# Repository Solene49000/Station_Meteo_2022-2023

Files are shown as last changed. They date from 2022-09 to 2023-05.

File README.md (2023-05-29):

INTRODUCTION
-
Dans le cadre du projet de la ruche connectée, nous continuons le développement de la station météo.
Celle ci permet  la mesure de données météorologiques telles que :
- La quantité de pluie tombée (1 front montant par basculement du pluviomètre)
- La vitesse du vent (1 front montant par tour d'anémomètre)
- La direction du vent (Tension différente par direction)
- La luminosité (I2C)
- La température (I2C)
- L'humidité (I2C)

Le code final nommé **test_sleep** est situé dans le repertoire : *Codes/Dernière version* : [https://github.com/Solene49000/Station_Meteo_2022-2023/tree/main/Codes/Derni%C3%A8re_version/test_sleep]

1 - LES PORTS
-

- Les ports LoRa
  - SCK : 18 -- Horloge SPI
  - MISO : 19 -- Master In Slave Out SPI
  - MOSI : 23 -- Master Out Slave In SPI
  - SS : 5 -- Select Slave = NSS SPI
  - RST : 14 -- Reset
  - DI0 : 26 -- Données
  
- Les ports de modules
  - ANEMOMETRE : 27 -- Récupère données anémomètre
  - PLUVIOMETRE : 32 -- Récupère données pluviomètre
  - GIROUETTE : 36 -- Récupère données girouette

- Autres ports
  - MEASURE : 13 -- Mettre à high pour fournir une tension aux modules
  - LED_R : 33 -- Led rouge de test du bon fonctionnement
  - LED_G : 25 -- Led verte de test du bon fonctionnement

2- LES FICHIERS
-
- test_sleep.ino : Demande à des fréquences régulières la restitution des données des modules et envoie la trame LoRa
- Girouette.ino : Renvoie la direction du vent entre 0 et 15 ( 0 = Nord, 1 = Nord Nord Ouest, ...)
- Anemometre.ino : Renvoie la vitesse du vent jusquà 250 km/h (float)
- Pluviometre.ino : Renvoie la quantité d'eau tombée en 10s
- LuxHumTemp.ino : 
  - Renvoie la luminosité en lux
  - Renvoie l'humidité en pourcentage
  - Renvoie la température en degrés
- ESP_LoRa_internal.ino : 
  - Appelle 3 fonctions
    - build_trame : écrit une trame avec les données brutes de nos mesures
    - debug_trame : reformate la trame en binaire
    - lora_send_trame : envoie la trame vers l'antenne
- Batterie.ino : Renvoie la tension de la batterie
 
3 - LES DETAILS
-
- Une trame LoRa est envoyée toutes les 15 minutes
- Structure trame :   I|macAdresse|pluviomètre|anémomètre|girouette|partie_1_pression|partie_2_pression|humidité|luminosité|température|batterie|checkbytes

4 - LE SET UP
-
- Télécharger Arduino IDE
- Télécharger toutes les librairies affichées dans le fichier concerné
- Paramétrer Arduino IDE pour accepter la carte ESP32 Dev Module
- Copier le code issu de github : ouvrir le terminal de commande, allez dans votre répertoire du projet et entrez la fonction suivante "git copy https://github.com/Solene49000/Station_Meteo_2022-2023/tree/main/Codes"
- Dans documents, ouvrir le fichier "Station_meteo.ino". Tous les fichiers du dossier s'ouvrent dans Arduino
- Préparer le set up :
  - Brancher le pluviomètre au connecteur P
  - Brancher l'anémomètre et la girouette au connecteur G
  - Brancher le câble USB à la carte Arduino et à votre PC
- Compiler puis téléverser le code ( La compilation peut s'avérer très longue car Arduino n'est pas vraiment adapté à Windows et nous avons un certain nombre de fichiers)

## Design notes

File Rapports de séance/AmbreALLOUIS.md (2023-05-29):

Rapport de séance
==

Présentation du projet
-

Séance du 01/09/2022
-

- Mise en place du projet Station Météo 2022-2023 :
  - Création du projet sur github
  - Ajout de dossiers : Rapports de séance et Docs
  - Ajout dans le dossier Docs de la documantation sur notre projet
  - Ajout des rapports de Solène Guillaume et Ambre Allouis dans Rapports de séance
  - Prise en main du langage Markdown
- Matériel à disposition :
  - Anémomètre : Vitesse du vent
  - Capteur de direction du vent
  - Pluviomètre : Compte le nombre de bascule
  - Capteur de lumière
  - Capteur de température, d'hydrométrie, de pression atmosphérique
  - Abris météo

Séance du 02/09/2022
-

- Récupération du schéma de la carte et du tableau.
- Lecture des rapports de l'année précédente
- Lecture des codes récupérés de l'année précédente : Les codes fournis ne sont pas bons, il manque la version finale.
- Installation et configuration d'Arduino :
  - Installation des librairies ESP32 et LoRa.
  - Analyse et compilation du code fourni
  - Choix du Port COM3
  - Outils : Carte ESP32 Dev
  - Création d'un code permettant de faire clignoter les deux led (LED_R et LED_G) pour vérifier l'accès à la carte.  

Séance du 09/09/2022
-

- On a recompilé le code permettant de faire alterner la led verte et la led rouge
- Pluie : détection par 1 front montant par routine + détection dès que la pluie tombe
- Vent changement : plusieurs fronts montant et descendants créés donc soit création d’un filtre et ou détection par rebond
- Pour la girouette : retourne 16 valeurs en fonction de la direction du vent. Les élèves précédents ont utilisé un générateur de tension. Chaque sortie est associée à une tension particulière. Le problème de ce fonctionnement est lié à la tension fournit par la batterie qui oscille entre 3,1 et 3,6 V. cet intervalle cause la proximité des tensions entre chaque sortie et fausse les résultats.
- M Peter nous a donc conseillé d’utiliser un générateur de courant car celui-ci n’est pas influencé par la différence de tension.

Séance du 15/09/2022
-

- Pluviometre, utilisation de la commande attachInterrupt() utilisation de la fonctionnalité FALLING permettant la dettection des fronts descendants
- cette fonction permet d'incrémenter une variable et de retourner chaque changement d'état
- le pluviometre est relie au port GIO 32, pour le fonctionnement initiale du pluviomêtre il reçoit V+. Pour notre cas, il est allimenté par VCC, donc pour obtenir la tension initiale, on pinMODE MEASURE à l'état 1 cette variable nous permet d'imposer le passage au niveau des transistor et ainsi de distribuer la bonne tension. Le transistor étant passant, le condo permet d'éviter l'é=effet de rebond. De plus lorsque la carte est débranchée puis rebranchée, le compteur  est incrémenté de 2.

anemo : installation de la librairie esp32 timerInterrupt

Séance du 03/10/2022
-

Codage de la partie Anémomètre :
- Recherche de bibliothèques timer associées à l'ESP32, nous ajoutons donc la bibliothèque ESP32TimerInterrupt
- Sans l'utilisation de cette bibliothèque, nous arrivons à afficher le nombre de tours de l'anémomètre et la vitesse du vent. en fin de séance nous nous sommes rendu compte que le calcul n'est pas correcte.
- Pour la réalisation de ce programme nous utilisaons la fonction delay. Le problème de cette fonction est que le programme est bloqué lors de sont activation. Donc cette fonction n'est pas compatible avec les autres codes.
- Le codage de l'anemomètre est en cours avec l'utilisation de la nouvelle librairie

Séance du 13/10/2022
-

- Utilisation de la bibliothèque ESP32TimerInterrupt :
  Cette bibliothèque nous permet de creer une fonction permettant l'interruption d'un programme à un moment donné dans une ISR. Pour notre cas, celle ci nous permet de relever la vitesse du vent. Pour notre cas d'essai, nous avons decidé de récupérer la vitesse toutes les 30 secondes.
  Pour la réalisation de cette fonction, nous avons utilisé les commandes suivantes :
    - My_timer = timerBegin(0, 80, true); --> Cette commande initialise la variable My_timer avec un numéro de timer, une valeur de prescaler et le mode compteur (true) 
    - timerAttachInterrupt(My_timer, &onTimer, true); --> Ici on fait appel à la fonction onTimer avec les paramètres de la variable My_timer
    - timerAlarmWrite(My_timer, tempsTimer*1000000, true); --> Maintenant, nous deffinissons le temps entre chaque interuption. Cette valeur est en microsecondes. Pour faciliter les calculs qui suivent, nous avons décidé de créer une variable comprenant le temps d'attente en secondes. Pour avoir le temps en microsecondes, nous multiplions cette variable avec la puissance associée (10^6).
    - timerAlarmEnable(My_timer); --> Activation de l'interruption
--> Nous avons fait le choix d'utiliser une librairie afin de clarifier et simplifier notre code lorsque toutes les parties seront réunies.
- Pour calculer la vitesse du vent, nous avons utilise=é le calcul suivant : vitesseVent = (PI * RAYON * 2 * tourAnemo)/tempsTimer*3.6 ;
  Nous multiplions la circonférence de l'anemomètre par le nombre de tours et le divisons par le temps en secondes. Le résultat obtenu est en m/s, nos le multiplions donc par 3.6 pour avoir ce résultat en km/h. 
- Le code de l'anémomètre est maintenant opérationnel et complet.

Séance du 28/10/2022
-

- installation de la librairie TSL2591 library
- installation de la librairie bluedot BME280 TSL2591
- Librairies BME hors de Arduino, recherche et téléchargement des dossiers nécéssaires

Séance du 18/11/2022
-

- Réalisation du code capteur de lumière

Séance du 25/11/2022
-

- Récupération du code de l'équipe de l'année dernière
- Installation de la librairie Adafruit
- Le code de l'année passé ne fonctionne pas, les valeurs globales : temperature, pression et humidite restent à 0. 

Séance du 01/12/2022
-

- Réalisation du code capteur de lumière et capteur de pression, humidité et température
- Installation des librairies :
  - Adafruit
  - ESP32 Time Interrupt
- Création du répertoire bibliothèques. Ce repertoire contient, un fichier texte avec la liste de toutes les bibliothèques installées et les fonctions qui les utilisent et les répertoires ".zip" à inclurent dans arduino.

Séance du 09/12/2022
-

- Finalisation du code capteur de lumière et capteur de pression, humidité et température
- La fonction interrupt / timer de l'ESP32, retourne des erreurs et empêche la bonne lecture des résultats.
  Le problème provient de la tension renvoyée par le système, elle est trop élevée.
  Au final, on a choisi de ne pas faire appel à cette fonction parce que pour le code final, on va récupérer toutes les données en mêmes temps. Pour cela, cette fonction ne nous sera pas utile.
- Mise en commun des codes et réalisation d'un main récupérant toutes les données à un interval de temps donné.

Séance du 20/12/2022
-

- Travail sur le système de récupération des données avec une trame LoRa
- LoRa : est un protocol réseau. Elle permet la modulation d'ondes radio et une transmission radio longue portée à bas débit. Cette technologie est la plus adaptée à notre système parce qu'on doit communiquer peu d'informations et peu souvent. Notre système est positionner à l'extérieur et doit communiquer avec une application située plus loin.
- Lors de cette séance, j'ai mal compris une de nos discussion. J'ai travaillé sur une interface web qui receptionne la trame LoRa. Cependant, l'application que nous devons rejoindre est déjà existante. Au final, j'ai perdu le temps d'une séance pour le projet.  

Séance du 06/01/2023
-

- Travail en binome sur la trame LoRa.
- Le code fourni n'est pas compilable, séance de débuggage.
- On relève un problème de fréquence pour la transmission.
- L'initialisation de la fréquance n'est pas fonctionnelle.
- La définition de type pour certaines fonctions était mal effectuée et provoquait des erreur : changement du type build en void.

Séance du 19/01/2023
-

- Présentation de notre avancée sur le projet
- Nous devons inclure dans notre code :
  - Lecture de la tension de le batterie et l'ajouter dans la trame LoRa
  - Ajouter un système de réveil. Celui-ci enverrai une fois réveillé toutes les données avec la trame LoRa et endormi compte le nombre de bascules du pluviomètre. 

Séance du 10/02/2023
-

- Choix du mode deep sleep car il consomme peu et il peut enregistrer des données même pendant sa phase endormie. 
- Le système est réveillé par toutes les interruptions.

Séance du 17/02/2023
-

Séance du 16/03/2023
-

Séance du 23/03/2023
-

- Ajout dans le code du sleep mode.
- Objectif : ne pas reveiller le systeme avec les bascules du pluviomètre.

Séance du 28/03/2023
-

- Utilisation du deep sleep, le microcontroleur, ne détecte pas les bascules.
- Test du slight sleep, fonctionne très bien, on arrive à récuperer le nombre de bascules. Mais le problème est que ce système consomme beaucoup trop.
- On bascule donc sur le deep sleep, le problème viendrait du code, il serait appelé au mauvais endroit.

Séance du 06/04/2023
-

- Comparaison entre l'heure du actuelle et l'heure de l'interruption pour compter les bascules.
- Fonctionnement du timer.

Séance du 20/04/2023
-

- Préparation du support de présentation
- On relève un problème lors du réveil du pluviomètre. Le deep sleep aurait un problème d'initialisation. Lors de la première mise en veille avant la première phase de réveil du système. Le deep sleep remonte bien le nombre de bascules du pluviomètre. Lors du premier réveil, la trame LoRa est bien transmise. Après commence la deuxième phase de mise en veille et là nous rencontrons un problème avec le temps de réveil. Ce problème provoque des bascules systématiques du pluviomètre.
- Nous avons remarqué que le temps d'interruption correspond toujours à celui de la première phase.

Séance du 27/04/2023
-

Présentation du projet

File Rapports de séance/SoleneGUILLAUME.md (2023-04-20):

CAHIER DE SUIVI - SOLENE GUILLAUME
==
SEANCE I - 01 Sept : Présentation du projet
-
Lots de cette séance, nous avons recu des explications sur le projet Ruche connectée. <br/> 

### Ruche connectée #

La ruche connectée est divisé en plusieurs projets différents. <br/>Notre promo prend la suite de ce qui est existant.
<br/> Trois grosses parties sont à créer ou bien à continuer.
- La station météo (à continuer)
- Lutte contre les parasites
- Communication GSM et WiFi

Nous nous occuperons de la partie station météo. <br/> 
Il nous faudra pour ceci créer une interface utilisateur affichant les données météorologiques captées. <br/>

### Matériel à disposition #
- Pluviomètre
- Anémomètre
- Girouette
- Capteur de luminosité (TSL2591)
- Capteur de température, d'hydrométrie et de pression atmosphérique (BME/BMP280)
- Microcontroleur ESP32 

### Avancées #

- Présentation du projet
- Choix du sujet
- Prise en main de Github
- Création du Repository sur Github
- Organisation du Repository
- Ajout des documents et liens utiles dans le repository
- Creation du fichier de cahier de suivi
- Prise en main du langage markdown 

SEANCE II - 02 Sept : Recupération des fichiers
-

- Recupération du schéma et du PCB 
  - Pluviomètre = connecteur gauche et girouette = connecteur droit
- Recupération du GitHub de l'année dernière
  - Lecture des documents 
- Sur Arduino : installation des libraires ESP32 et LoRa
- Outils : Carte ESP32 Dev et Port COM3
- Test des codes donnés l'année dernière : ne fonctionnent pas
- Creation d'un code pour tester compilation et bon fonctionnement de la carte : les leds s'allument

SEANCE III - 09 Sept : Commencement du code du pluviomètre
-
- Recompilation du code des Leds sur Arduino
- Separation des taches
  - Ambre : Pluviomètre et Anémomètre
  - Solène : Girouette  
- Lien pour infos du materiel https://www.lextronic.fr/anemometre-pluviometre-girouette-compatible-arduino-microbit-grove-63661.html
- Lien pour code Arduino sur le matériel : http://atelier-meteo-arduino-lycee-vincendo.blogspot.com/p/le-pluviometre.html
- La Girouette donne 16 valeurs selon la direction d'où vient le vent
  - Impossible de téléverser le code
  - L'année dernière, les eleves ont fait un pont diviseur de tension. En le testant, il est apparu que les mesures de tension prises n'ont pas satisfait car trop proches. 
  - A la place, Monsieur Peter nous a conseillé de renmplacer la résistance principale par un générateur de courant.
  - Les prochaines séances, nous allons nous concentrer sur les autres appareils.
 - Concernant le pluviomètre et l'anémomètre :
  -   l'interrupeur fait des rebonds. Il faut pour ceci faire en sorte dans notre code de ne pas prendre en compte ces faux rebonds pour ne pas fausser la mesure.

SEANCE IV - 15 Sept : Pluviomètre
-
- Probleme sur pluviomètre : Ne detectait pas les fronts montants
  - Avec l'aide de M. Peter, de l'oscilloscope et du schéma, nous avons compris que V+ n'etait pas assez alimenté
  - Ceci car des transistors étaient bloqués. Il faut les rendre passants. Sur arduino : mettre la pin MEASURE à HIGH
  - Maintenant V+ est alimenté et les transitions 0 --> 1 franches. Le code marche et nous arrivons à avoir un compte des clics.
- Grace à l'ajout l'année dernière d'un condensateur, nous n'avons plus de rebonds entre chaque incrémentation. Le compte est propre.
- Pour l'anemometre : nous arrivons compter les switchs. Il faut maintenant reflechir à un code viable pour compter les switchs : interruption de timer otutes les secondes

SEANCE V - 3 oct : Anemomètre et Girouette
-
- Sur mon ordi : probleme avec le port COM3. Pendant le téléversement, un message d'erreur apparaît. IL faut mettre en loader pile au message "Connecting...."
- Pour palier le probleme, essai de telecharger Arduino et de otut reinstaller sur ma VM linux : finalement inutile puisque probleme en partie résolu et impossible car pas assez d'espace de stockage sur la VM
- Ambre a continué sur l'anémomètre
- J'ai commencé sur la girouette :
  - Il faut mettre le MEASURE à HIGH avant de declarer tout le reste dans la boucle set up
  - Je peux récupérer des valeurs de la girouette mais elle ne dépendent pas de la position de la girouette et se décrémentent de 255 à 0.  

SEANCE VI - 13 octobre : Anémomètre et Girouette
-
- Lien github de station meteo : https://github.com/StationMeteoDIY
- Girouette : un pont diviseur de tension ne convient pas car la tension est instable. Il nous faut alors un generateur de courant.
- Nous choisissons le LM334DT que nous programmerons pour générer un courant de 0,01 mA (La resistance equivalente max etant de 120K)
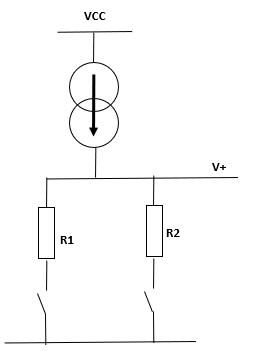
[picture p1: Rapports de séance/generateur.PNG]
-
- Prochaine seance : faire le schema et souder sur la carte ? (ne pas oublier d'enlever la resistance du pont diviseur de tension originel)

SEANCE VII - 28 Octobre : Girouette (Générateur de courant) et BME280
-
- Schéma et board Eagle du petit module générateur de courant finis. PCB usiné pour la semaine prochaine.
- Commencé le code du BME280. Mais n'arrive pas à le compiler (Problème de librairie ?)

SEANCE VIII - 25 Novembre : Girouette
-
- Module générateur de courant testé. Valeurs de tension stockées dans un excel
- Module soudé sur le board principal
- Test du module : des valeurs autres que celles de la tension sortent sur la console. Nous en avons 16, stockées sur un tableau excel
- Pour la prochaine fois : finir le code (indiquer la direction de la girouette pour chaque valeur)

SEANCE X - 01 Décembre : Makefile
-
- Girouette fonctionnelle et envoie les données désirées.
- Installation de la commande make sur Windows. Voici la procédure : 
  - Ouvrir le terminal de commande en administrateur 
  - Installer chocolatey en saisissant la commande suivante : `@"%SystemRoot%\System32\WindowsPowerShell\v1.0\powershell.exe" -NoProfile -InputFormat None -ExecutionPolicy Bypass -Command "[System.Net.ServicePointManager]::SecurityProtocol = 3072; iex ((New-Object System.Net.WebClient).DownloadString('https://community.chocolatey.org/install.ps1'))" &amp;&amp; SET "PATH=%PATH%;%ALLUSERSPROFILE%\chocolatey\bin"`
  - Fermer et rouvrir le terminal de commande en administrateur
  - Installer la commande make en saisissant : `choco install make`
  - Fermer et rouvrir l'invite de commande avant de faire un make
 - Finalement tout ceci inutile car pas besoin d'un makefile sur arduino : https://arduino.stackexchange.com/questions/60656/split-up-arduino-code-into-multiple-files-using-arduino-ide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,the%20rest%20of%20the.ino%20files%20in%20alphabetical%20order.
 - Code d'Ambre pour luminosité, pression, température et humidité foncionnel -> besoin d'installer la librairie BME 280 sur mon PC

SEANCE XI - 09 Décembre : Makefile
-
- "Makefile" terminé
  - Actualisation des valeurs toutes les 10 secondes
- Compilation très longue
  - Intallation d'Arduino sur VM linux : Compilation très rapide mais pas moyen d'utiliser une board ESP32 sur l'IDE :-(
- Prochaine séance : Mettre en forme les données pour les envoyer via LoRa 

SEANCE XII - 20 Décembre : LoRa
-
- Début de mise en forme des données pour LoRa
  - Recupération du code de l'année dernière
  - Erreur lecture numéro MAC -> résolue en trouvans une autre manière d'obtenir le numéro MAC de l'ESP32
  - Erreur ESP32 -> outil installé pour décoder les erreurs ESP32 : ESP Exception Decoder
    - L'outil est utile pour les messages chiffrés de l'ESP32
    - Relativement imprécis sur l'explication de l'erreur mais aide tout de même
   
SEANCE XIII - 06 Janvier : LoRa
-
- Erreur ESP32 : Déclaration du type de la fonction build_trame incorrecte (uint_t -> void) dans le code de l'année dernière. Probleme résolu
- Nous arrivons à créer une trame LoRa avec des valeurs prédéfinies
- Nous avons un message d'erreur de problème d'initialisation de fréquence à régler lors de la prochaine séance

SEANCE XIV - 19 Janvier : Présentation des projets
-
- Apres la trame LoRa, nous devrons nous intéresser à consommer le minimum possible.
  - Il nous faut mettre tous nos outils périphériques en sommeil ainsi que l'ESP32
  - Le système se réveille toutes  les 15 minutes ou bien lorsque nous avons un front montant du pluviomètre
- Le projet de batterie rechargeable par panneau solaire rencontre des difficultés en terme de conception de la carte

SEANCE IX - 10 fevrier : Low power modes
-
- Choix du mode low power :
   - mode light sleep : plus de communication sans fil (Bluetooth, WiFi,...)
   - mode deep sleep : plus de CPU, de communications sans fil ou de périphériques. Peut se réveiller par interruption ou après un temps donné
   - mode hibernate : plus de mémoire mais on en a besoin pour mémoriser les valeurs de pluie
- Nous choisissons finalement le mode deep sleep qui nous permet une connsommation amoindrie à 0,1mA au lieu de 60mA pour le mode actif.
- Lien pour avoir les codes pour passer en sleep : https://randomnerdtutorials.com/esp32-deep-sleep-arduino-ide-wake-up-sources/
- Il nous faut ne pas modifier le temps avant reveil initial (15 min) si nous avons la pluie qui interrompt le sleep

SEANCE X - 17 fevrier
-
- Debug du ESP sleep : erreurs dues à l'activation de la pin measure
  - Les peripheriques causent une chute de tension lors de leur alimentation 
  - Premiere solution : une capa plus puissante pour compenser la chute de tension -> pas suffisant
  - Deuxieme solution : alimentation 5V en externe a explorer a la prochaine seance  

SEANCE XI - 16 Mars
-
- Debug du ESP Sleep
   - Alimentation 5V externe -> L'ESP se réveille à chaque timer mais pas sous l'action du pluviometre
   - Le pluviometre n'est plus alimenté via la pin measure lorsque l'esp passe en sleep
   - Essais de pullup internes etc -> pas fonctionnels
   - Changement de câblage : le pluviomètre est maintenant alimenté par VCC et non par V+ via R3
   -  Prochaine seance : fusionner le code de passage en sleep avec tout le reste du code + ne pas perturber le timer si reveil par pluviometre.

SEANCE XII - 23 Mars
-
- Tests passage en sleep mode sans perturber le reveil toutes les 25 secondes par l'action du pluviomètre.
  - partie à developper à la prochaine séance.
 
SEANCE XII - 28 Mars
-
- Ne pas perturber le timer si reveil par pluviometre :
  - test de plusieurs possibilités non fonctionelles avant de constater que le delta time ne bouge pas
  - Fonctionel en slight sleep mais on peut mieux faire
  - prochaine seance : utiliser l'heure du systeme

SEANCE XII - ??
-
- Le timer fonctionne même apres deux ou trois bascules

SEANCE XIV - 20 Avril
-
- Le deep sleep ne fonctionne pas : "Guru panic'ed"
  - Erreur peut etre sur l'ordre : on appelle l'envoi LoRa avant l'initialisation de LoRa
- Réecriture du code dans le setup() pour ne pas appeler l'initialisation de LoRa quans reveil par le pluviometre.
- En réglant ces problèmes, nous n'arrivons maintenant plus à récupérer les données ni à gérer correctement le réveil du timer 
- 
-

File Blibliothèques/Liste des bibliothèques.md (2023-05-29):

# Liste des Bibliothèques utilisées dans nos codes

| Bibliothèques | Codes | Nom de la bibliothèque dans Arduino |
|---|---|---|
| ESP32TimerInterrupt.h | test_sleep.ino | ESP32TimerInterrupt |
| ESP32TimerInterrupt.hpp | test_sleep.ino | ESP32TimerInterrupt |
| Adafruit_BME280.h | test_sleep.ino | Adafruit BME280 Library |
| Adafruit_Sensor.h | test_sleep.ino | Adafruit Unified Sensor |
| Adafruit_TSL2591.h | test_sleep.ino | Adafruit TSL2591 Library |
| Adafruit_BusIO_Register.h | test_sleep.ino | Adafruit BusIO |
| Adafruit_I2CDevice.h | test_sleep.ino | Adafruit BusIO |
| Adafruit_I2CRegister.h | test_sleep.ino | Adafruit AM2320 sensor library |
| Adafruit_SPIDevice.h | test_sleep.ino | Adafruit BusIO |
| Arduino.h | LoRa.h | Arduino |
| SPI.h | LoRa.h | SPI |

La bibliothèque : Adafruit Unified Sensor n'est pas présente sur Arduino. Il faut inclure le répertoire ZIP : "Adafruit_Unified_Sensor-1.1.6.zip" dans les librairies Arduino.

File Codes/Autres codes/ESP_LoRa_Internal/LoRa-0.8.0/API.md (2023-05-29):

# LoRa API

## Include Library

```arduino
#include <LoRa.h>
```

## Setup

### Begin

Initialize the library with the specified frequency.

```arduino
LoRa.begin(frequency);
```
 * `frequency` - frequency in Hz (`433E6`, `868E6`, `915E6`)

Returns `1` on success, `0` on failure.

### Set pins

Override the default `NSS`, `NRESET`, and `DIO0` pins used by the library. **Must** be called before `LoRa.begin()`.

```arduino
LoRa.setPins(ss, reset, dio0);
```
 * `ss` - new slave select pin to use, defaults to `10`
 * `reset` - new reset pin to use, defaults to `9`
 * `dio0` - new DIO0 pin to use, defaults to `2`.  **Must** be interrupt capable via [attachInterrupt(...)](https://www.arduino.cc/en/Reference/AttachInterrupt).

This call is optional and only needs to be used if you need to change the default pins used.

#### No MCU controlled reset pin

To save further pins one could connect the reset pin of the MCU with reset pin of the radio thus resetting only during startup.

* `reset` - set to `-1` to omit this pin

#### Pin dio0 interrupt callbacks

The dio0 pin can be used for transmission finish callback and/or receiving callback, check `onTxDone` and `onReceive`.

### Set SPI interface

Override the default SPI interface used by the library. **Must** be called before `LoRa.begin()`.

```arduino
LoRa.setSPI(spi);
```
 * `spi` - new SPI interface to use, defaults to `SPI`

This call is optional and only needs to be used if you need to change the default SPI interface used, in the case your Arduino (or compatible) board has more than one SPI interface present.

### Set SPI Frequency

Override the default SPI frequency of 10 MHz used by the library. **Must** be called before `LoRa.begin()`.

```arduino
LoRa.setSPIFrequency(frequency);
```
 * `frequency` - new SPI frequency to use, defaults to `8E6`

This call is optional and only needs to be used if you need to change the default SPI frequency used. Some logic level converters cannot support high speeds such as 8 MHz, so a lower SPI frequency can be selected with `LoRa.setSPIFrequency(frequency)`.

### End

Stop the library

```arduino
LoRa.end()
```

## Sending data

### Begin packet

Start the sequence of sending a packet.

```arduino
LoRa.beginPacket();

LoRa.beginPacket(implicitHeader);
```

 * `implicitHeader` - (optional) `true` enables implicit header mode, `false` enables explicit header mode (default)

Returns `1` if radio is ready to transmit, `0` if busy or on failure.

### Writing

Write data to the packet. Each packet can contain up to 255 bytes.

```arduino
LoRa.write(byte);

LoRa.write(buffer, length);
```
* `byte` - single byte to write to packet

or

* `buffer` - data to write to packet
* `length` - size of data to write

Returns the number of bytes written.

**Note:** Other Arduino `Print` API's can also be used to write data into the packet

### End packet

End the sequence of sending a packet.

```arduino
LoRa.endPacket();

LoRa.endPacket(async);
```
 * `async` - (optional) `true` enables non-blocking mode, `false` waits for transmission to be completed (default)

Returns `1` on success, `0` on failure.

### Tx Done

**WARNING**: TxDone callback uses the interrupt pin on the `dio0` check `setPins` function!

### Register callback

Register a callback function for when a packet transmission finish.

```arduino
LoRa.onTxDone(onTxDone);

void onTxDone() {
 // ...
}
```

 * `onTxDone` - function to call when a packet transmission finish.

## Receiving data

### Parsing packet

Check if a packet has been received.

```arduino
int packetSize = LoRa.parsePacket();

int packetSize = LoRa.parsePacket(size);
```

 * `size` - (optional) if `> 0` implicit header mode is enabled with the expected a packet of `size` bytes, default mode is explicit header mode

Returns the packet size in bytes or `0` if no packet was received.

### Continuous receive mode

**WARNING**: Receive callback uses the interrupt pin on the `dio0`, check `setPins` function!

#### Register callback

Register a callback function for when a packet is received.

```arduino
LoRa.onReceive(onReceive);

void onReceive(int packetSize) {
 // ...
}
```

 * `onReceive` - function to call when a packet is received.

#### Receive mode

Puts the radio in continuous receive mode.

```arduino
LoRa.receive();

LoRa.receive(int size);
```

 * `size` - (optional) if `> 0` implicit header mode is enabled with the expected a packet of `size` bytes, default mode is explicit header mode

The `onReceive` callback will be called when a packet is received.

### Packet RSSI

```arduino
int rssi = LoRa.packetRssi();
```

Returns the averaged RSSI of the last received packet (dBm).

### Packet SNR

```arduino
float snr = LoRa.packetSnr();
```

Returns the estimated SNR of the received packet in dB.

## RSSI

```arduino
int rssi = LoRa.rssi();
```

Returns the current RSSI of the radio (dBm). RSSI can be read at any time (during packet reception or not)

### Packet Frequency Error

```arduino
long freqErr = LoRa.packetFrequencyError();
```

Returns the frequency error of the received packet in Hz. The frequency error is the frequency offset between the receiver centre frequency and that of an incoming LoRa signal.

### Available

```arduino
int availableBytes = LoRa.available()
```

Returns number of bytes available for reading.

### Peeking

Peek at the next byte in the packet.

```arduino
byte b = LoRa.peek();
```

Returns the next byte in the packet or `-1` if no bytes are available.

### Reading

Read the next byte from the packet.

```arduino
byte b = LoRa.read();
```

Returns the next byte in the packet or `-1` if no bytes are available.

**Note:** Other Arduino [`Stream` API's](https://www.arduino.cc/en/Reference/Stream) can also be used to read data from the packet

## Other radio modes

### Idle mode

Put the radio in idle (standby) mode.

```arduino
LoRa.idle();
```

### Sleep mode

Put the radio in sleep mode.

```arduino
LoRa.sleep();
```

## Radio parameters

### TX Power

Change the TX power of the radio.

```arduino
LoRa.setTxPower(txPower);

LoRa.setTxPower(txPower, outputPin);
```
 * `txPower` - TX power in dB, defaults to `17`
 * `outputPin` - (optional) PA output pin, supported values are `PA_OUTPUT_RFO_PIN` and `PA_OUTPUT_PA_BOOST_PIN`, defaults to `PA_OUTPUT_PA_BOOST_PIN`.

Supported values are `2` to `20` for `PA_OUTPUT_PA_BOOST_PIN`, and `0` to `14` for `PA_OUTPUT_RFO_PIN`.

Most modules have the PA output pin connected to PA BOOST,

### Frequency

Change the frequency of the radio.

```arduino
LoRa.setFrequency(frequency);
```
 * `frequency` - frequency in Hz (`433E6`, `866E6`, `915E6`)

### Spreading Factor

Change the spreading factor of the radio.

```arduino
LoRa.setSpreadingFactor(spreadingFactor);
```
 * `spreadingFactor` - spreading factor, defaults to `7`

Supported values are between `6` and `12`. If a spreading factor of `6` is set, implicit header mode must be used to transmit and receive packets.

### Signal Bandwidth

Change the signal bandwidth of the radio.

```arduino
LoRa.setSignalBandwidth(signalBandwidth);
```

 * `signalBandwidth` - signal bandwidth in Hz, defaults to `125E3`.

Supported values are `7.8E3`, `10.4E3`, `15.6E3`, `20.8E3`, `31.25E3`, `41.7E3`, `62.5E3`, `125E3`, `250E3`, and `500E3`.

### Coding Rate

Change the coding rate of the radio.

```arduino
LoRa.setCodingRate4(codingRateDenominator);
```

 * `codingRateDenominator` - denominator of the coding rate, defaults to `5`

Supported values are between `5` and `8`, these correspond to coding rates of `4/5` and `4/8`. The coding rate numerator is fixed at `4`.

### Preamble Length

Change the preamble length of the radio.

```arduino
LoRa.setPreambleLength(preambleLength);
```

 * `preambleLength` - preamble length in symbols, defaults to `8`

Supported values are between `6` and `65535`.

### Sync Word

Change the sync word of the radio.

```arduino
LoRa.setSyncWord(syncWord);
```

 * `syncWord` - byte value to use as the sync word, defaults to `0x12`

### CRC

Enable or disable CRC usage, by default a CRC is not used.

```arduino
LoRa.enableCrc();

LoRa.disableCrc();
```

### Invert IQ Signals

Enable or disable Invert the LoRa I and Q signals, by default a invertIQ is not used.

```arduino
LoRa.enableInvertIQ();

LoRa.disableInvertIQ();
```
### LNA Gain

Set LNA Gain for better RX sensitivity, by default AGC (Automatic Gain Control) is used and LNA gain is not used.

```arduino
LoRa.setGain(gain);
```

 * `gain` - LNA gain

Supported values are between `0` and `6`. If gain is 0, AGC will be enabled and LNA gain will not be used. Else if gain is from 1 to 6, AGC will be disabled and LNA gain will be used.

## Other functions

### Random

Generate a random byte, based on the Wideband RSSI measurement.

```
byte b = LoRa.random();
```

Returns random byte.

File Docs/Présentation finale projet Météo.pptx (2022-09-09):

## Présentation Projet Météo

Polytech ITII

Projet Ruche - Module station météorologique

GAGLIO² / DENIAUD

## Sommaire

1. Description du projet
  a. Présentation générale
  b. Module station météo
2. Comparatif Planning prévisionnel / réel
  a. Planning prévisionnel
  b. Planning réel
3. Fonctionnalités validées
  a. Hardware
  b. Software
4. Bilans perspectives

## Description du projet

a. Présentation générale

Contexte : Création d’une ruche interconnectée, avec un suivi à distance de diverses données :

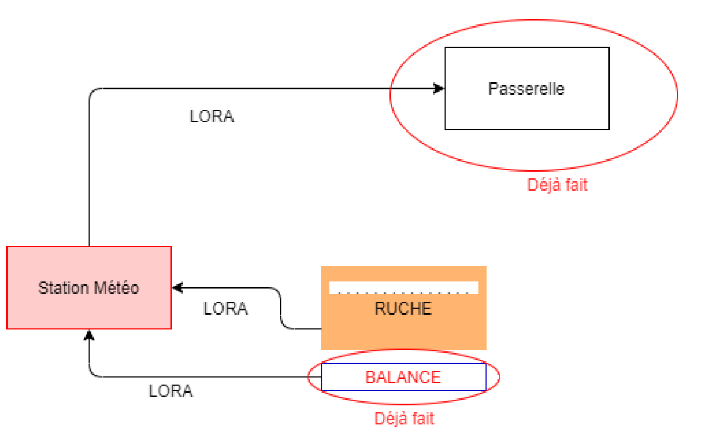
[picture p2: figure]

## Description du projet

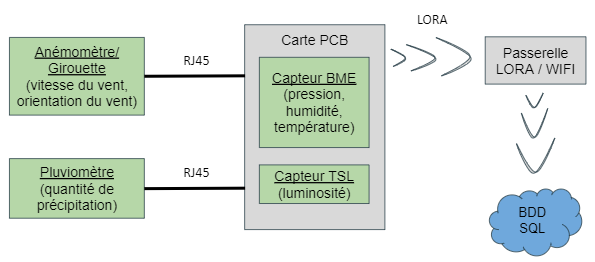
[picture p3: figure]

a. Module Station Météo :

Objectifs :
- Relever la température.
- Relever l’humidité.
- Relever la pression atmosphérique.
- Relever la luminosité.
- Relever la pluviométrie.
- Relever les caractéristiques du vent ( direction et vitesse ).
- Transmettre périodiquement à une BDD toutes ces données.

## Description du projet

a. Module Station Météo :

Anémomètre

Tension

Girouette

ESP32

SPI

Module LORA

Interruption

Pluviomètre

I2C

Capteur TSL

Capteur BME

## 2) Planning prévisionnel / réel

a. Planning prévisionnel :

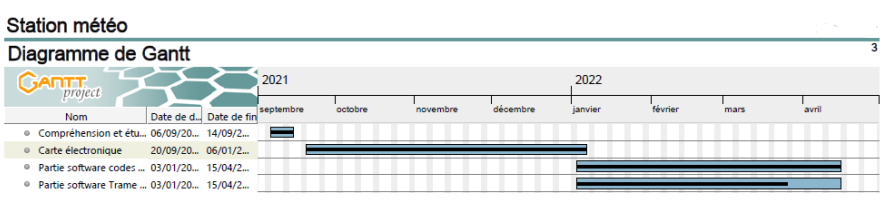
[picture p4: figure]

## 2) Planning prévisionnel / réel

a. Planning réel :

Semestre 7 :
- Création de la carte électronique PCB
Semestre 8 :
- Réalisation de la partie software pour la récupération des données
- Réalisation de la partie software pour la transmission des données
- Modification carte électronique et montage sur breadboard

## 3) Fonctionnalités validées

a. Partie hardware

→ Récupération du schéma Eagle effectuée par la promotion précédente :
→ Récupération de l’empreinte du connecteur RJ45 → Ajout de 2 connecteur RJ45 femelle pour connecter les modules Anémomètre/Girouette et Pluviomètre
→ Correction du routage du bottom/top de la carte sur Eagle
→ Suppression/ajout de routes, ajout de vias, optimisation de la carte.
→ Création de la carte PCB (brasage..)
→ Tests sur la carte PCB

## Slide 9

Schéma EAGLE :

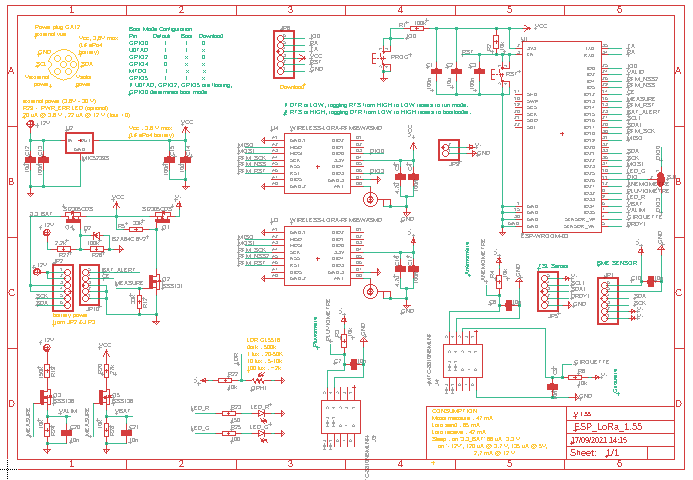
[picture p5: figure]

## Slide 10

Schéma PCB :

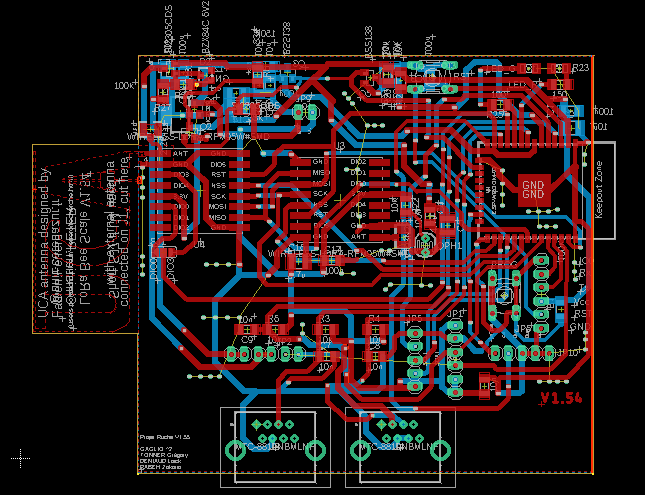
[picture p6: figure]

## Brasage des composants

→ Réception du PCB de notre carte électronique
-> Brasage des composants CMS sur le PCB avec un calque dans le four à refusion pour le devant de la carte.
-> Brasage à la main au fer à souder des composants CMS restant au dos de la carte.

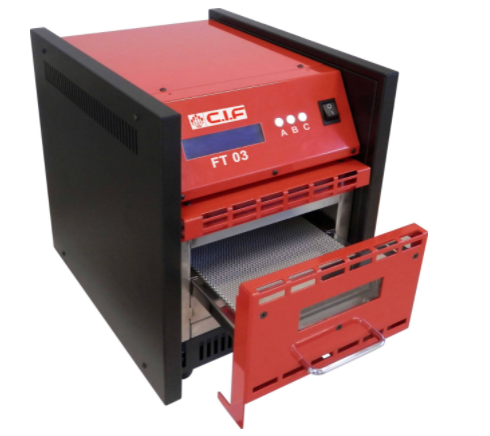
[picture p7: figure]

## Brasage des composants

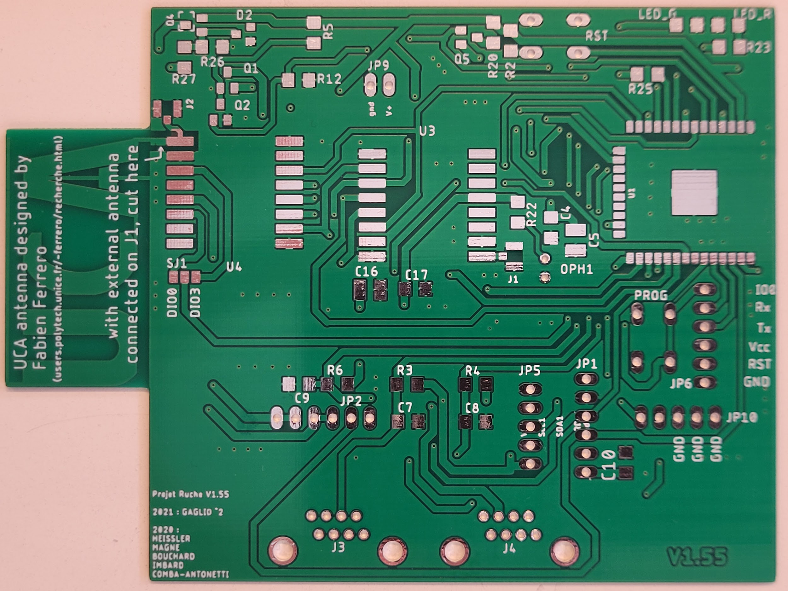
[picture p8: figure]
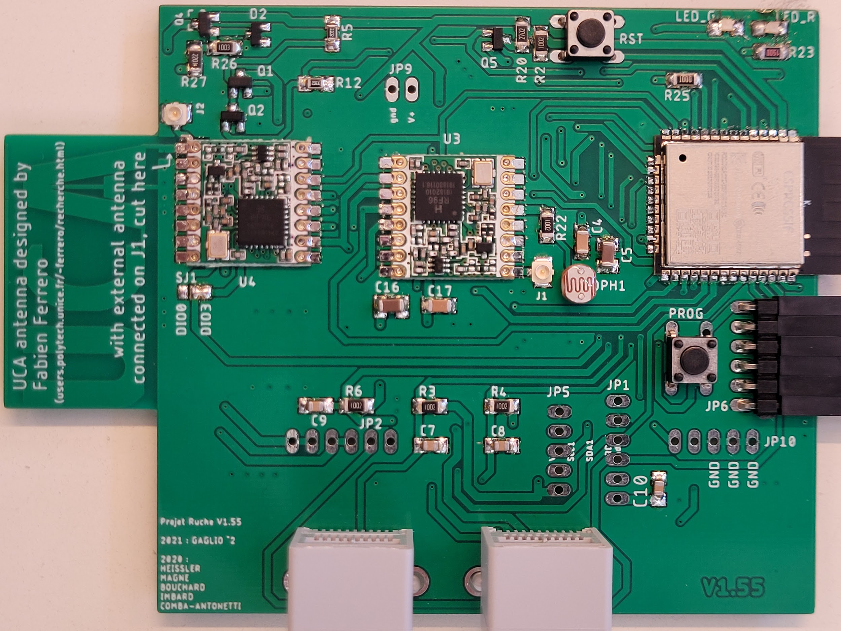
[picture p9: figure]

## Tests de la carte PCB

→ Test de fonctionnement des 2 LED R/G pilotées par l’ESP32 avec un code Arduino.
-> Test des codes de récupération des informations des capteurs LST et BME.
-> Test de fonctionnement des modules météo avec oscillateur.

## Capteurs BME280 et TSL2591

Contexte et Objectif : Les trous effectués pour positionner et braser les capteurs à notre PCB n’avaient pas été correctement définis. L’objectif était de trouver une solution pour pallier le problème.
-Ajout des capteurs sur la carte PCB (collage).
-Brasage des capteurs sur la carte PCB.
-Remaniement de la carte par M.Peter
-Transistor bloquant la Tension vers les capteurs -> Réveiller la PIN correspondante
Sur l’ESP.
Conclusion : Grâce aux tâches effectuées ci-dessus, nous arrivons à récupérer les données des capteurs présents sur la carte PCB. Objectif atteint.

## Capteurs BME280 et TSL2591

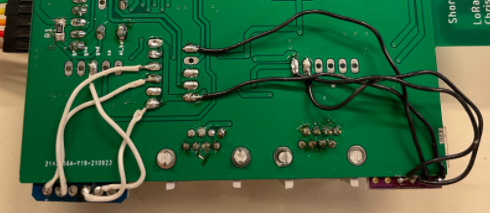
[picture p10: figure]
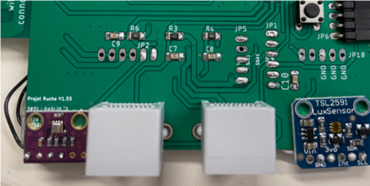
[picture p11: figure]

## Câblage breadboard et tests

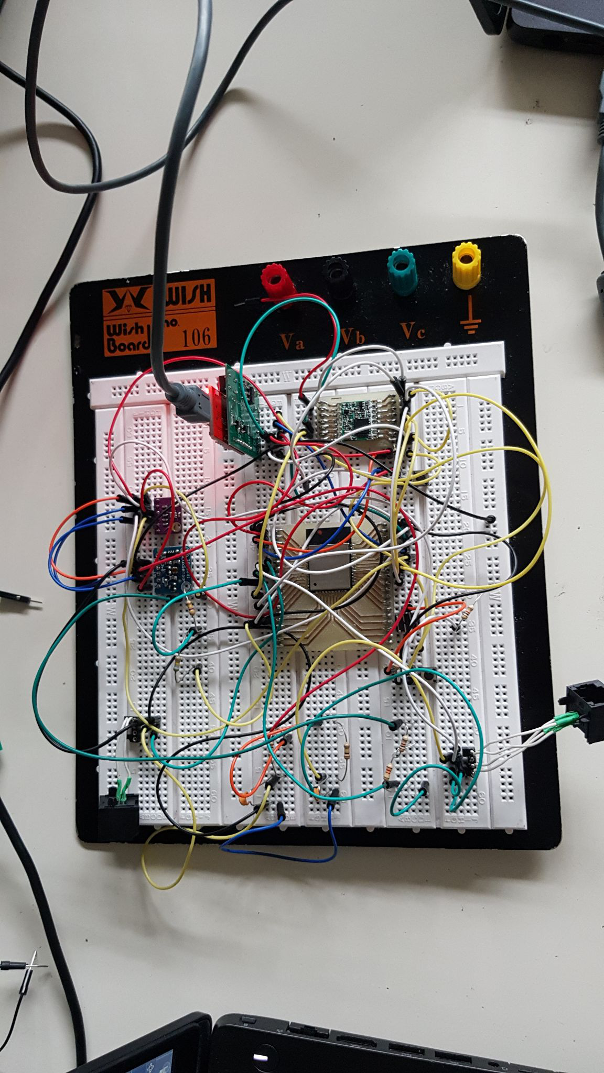
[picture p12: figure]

- Câblage des capteurs et module météo pour test des codes logiciels
- Brasage de connecteurs RJ11 pour module météo
- Redimensionnement des Résistances et Condensateurs pour le module météo

## 3) Fonctionnalités validées

b) Partie Software

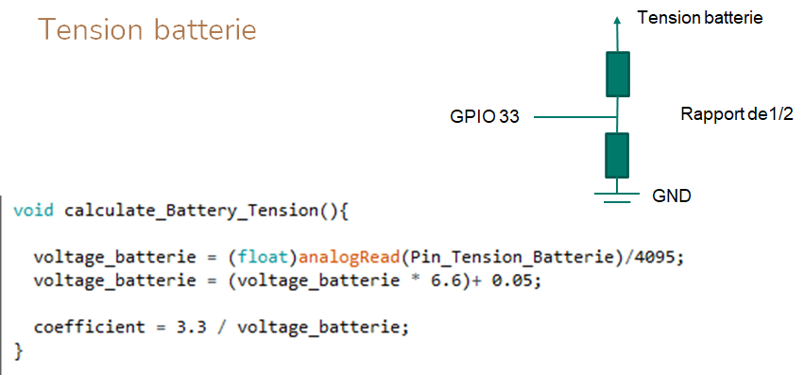
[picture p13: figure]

## 3) Fonctionnalités validées

b) Partie Software

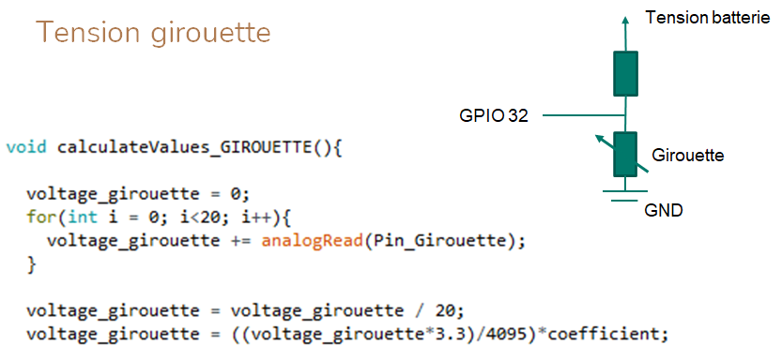
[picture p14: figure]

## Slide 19

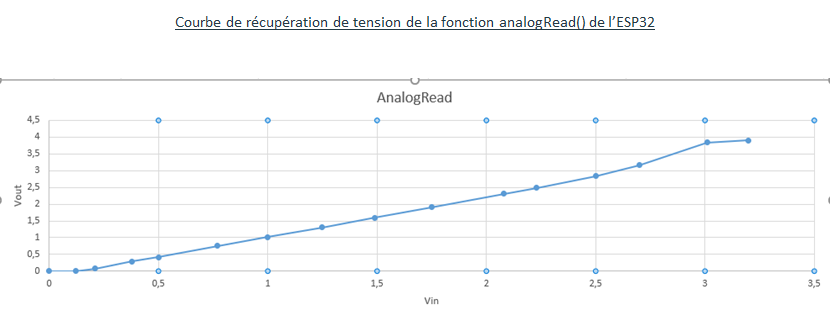
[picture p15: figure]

## 3) Fonctionnalités validées

b) Partie Software

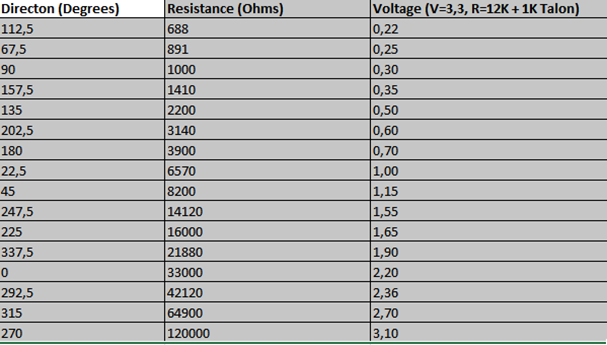
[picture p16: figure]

## 3) Fonctionnalités validées

b) Partie Software

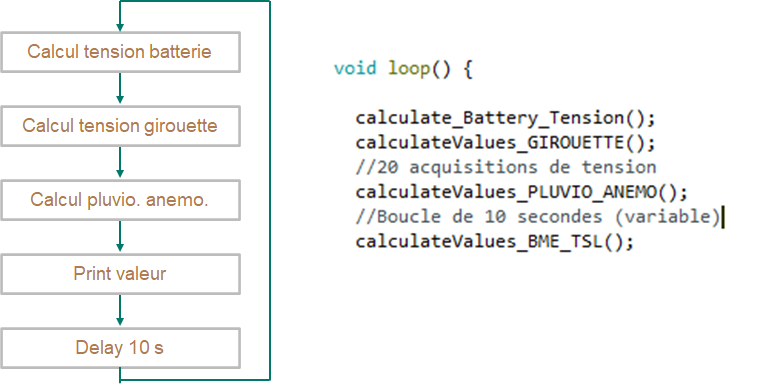
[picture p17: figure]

## 3) Fonctionnalités validées

b) Partie Software

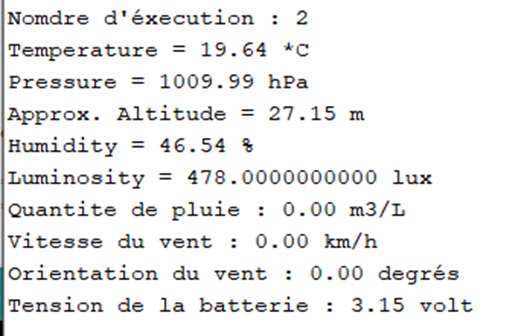
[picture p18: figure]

## Communication Lora/Passerelle

Contexte et Objectif : Afin de pouvoir utiliser les données de nos équipements il faut effectuer une communication entre notre carte PCB et une passerelle externe. L’objectif de cette partie était donc de trouver une méthode afin de pouvoir communiquer une trame de notre Lora à la Passerelle.
- Récupération d’une passerelle fonctionnant auprès de Monsieur Peter.
- Ecriture d’un code arduino permettant la connexion et la communication entre notre Lora et la passerelle.
- Test d’envoi d’une trame de données avec des données fixes, écriture d’une procédure

## Capteurs BME et TSL

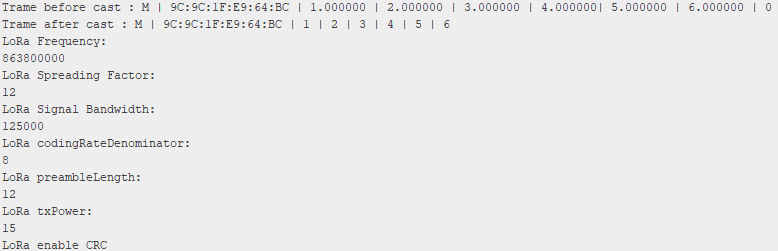
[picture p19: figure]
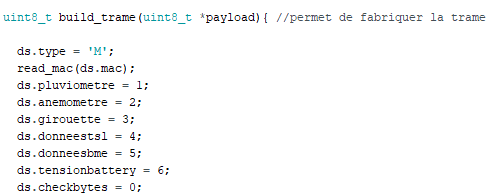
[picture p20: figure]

## Bilan / Perspectives

- Développement de compétences en électronique appliquée (brasage, routage, etc).
- Développement de compétences en informatique (codage en langage C sur Arduino pour la gestion des capteurs/trame).
- Mise en application de la gestion de projet et du travail en équipe.
- Satisfait du résultat final mais à terminer.

## Bilan / Perspectives

- Carte électronique avec composants et capteurs brasés fonctionnelle.
- Codes valides de récupération des informations des capteurs.
- Envoi de trames entre passerelle et Lora.

Tâches fonctionnelles :

## Bilan / Perspectives

- Carte électronique à revoir en fonction de la breadboard.
- Gestion de la trame à terminer.
- Gestion du mode sommeil.

Tâches à continuer :

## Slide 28

## Bilan / Perspectives

Gestion de la trame à terminer :
Température : 2 chiffres après la virgule à 2 bytes signed
Pression atmosphérique à 2 bytes unsigned
Humidité à 1 bytes unsigned
Luminosité à 3 bytes unsigned
Quantité de pluie à 2 bytes unsigned
Vitesse du vet à 1 bytes unsigned
Orientation du vent à 1 bytes unsigned
Tension de la batterie à 2 bytes unsigned

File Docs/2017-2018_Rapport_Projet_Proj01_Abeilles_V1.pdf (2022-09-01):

# Projets Industriels – Elec4

# Année scolaire 2017-2018

# Rapport de Projet

# ″Bee Connect, La ruche connectée″

## ″Version 1″

# Etudiants : Dihia Bitam, Qingna Xue, Axel Le Bourhis

# Encadrant : Pascal Masson

Ecole Polytechnique Universitaire de Nice Sophia-Antipolis, Département électronique 930 route des Colles, 06410 BIOT

# THANKS

The BeeConnect team would like to address its special thanks to Mr Masson, the project tutor and professor at Polytech, for his advices, his follow-up and his trust.

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
I.1.1

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
I.1.1.1

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
I.1.1.2

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
I.1.1.3

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
I.1.2

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
I.1.3

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
I.1.3.1

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
I.1.3.2

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
I.1.3.3

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
I.2.1

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
I.2.1

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
I.3.1

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
I.3.1.a

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
I.3.1.b

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
I.3.1

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
I.4.a

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
I.4.b

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
V.2.1

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
# Introduction

BeeConnect is a project that is part of our teaching in the second semester of our 4th year in electronics studies. In a few words, it consists in setting up a system which will allow users to monitor a beehive.

Before tackling the technical aspect of this project, it is important to know its interest and what could we benefit from it.

It is known that bees are crucial elements of our environment. They are essential for biodiversity and the development of agriculture. In fact, they pollinate about 80% of plant species, which contributes to the survival, the evolution and the production of plant species. The decline of bees population is mainly because of pesticides, disease, parasites, and poor weather due to global warming. The monitoring of a beehive can really help prevent loss and keep track of the bee’s health.

Our goal is to build, through a series of sensors and warning indicators, a connected hive. The data collected will be processed and sent to a dedicated website, where users can see the activity of the bees during the day/night depending on the influence of some climate factors such as temperature, humidity, brightess, air pressure… The webpage will also indicate the variation of the hive’s weight, the number of bees and show a real time video of the hive.

This report will treat of how went our projet. We’ll start with the specifications we had to meet, we’ll continue with our achievement and failures with the sensors and how we dealt with data sending over the internet. Then we treat of the physical implementation of the sensors and the system itself. Finally we will end with how we planned our project, what is its actual status and what we would like to do in the future.

# Chapter I : Specifications

The goal of the project is to make a smart beehive. The beehive will have to provide information like temperature, humidity, atmospheric pressure, weight and brightness. These data will be sent to a webpage and will be available for everyone.

All the data will be processed by an Arduino or a STM Nucleo card. We will use WiFi to send the data to the website. We also will have to use IP cameras to send pictures of the beehive to the webpage so everyone can see it in real time.

We have to remember that the system is outside, so we’ll have to keep it safe from weather. We don’t have any constraints about the energy consumption as the project is a first experience and we just need to see if it’s feasible.

Here are the main functions as well as the constraints functions which give a first overall view of the project:

FP1: To measure temperature and humidity

FP2: To measure the weight of the hive

FP3: To measure the brightness

FP4: To measure the atmospheric pressure

FP5: Counting the bees going in and out

FP6: Taking pictures of the beehive

FP7: Collecting data coming from the sensors on a website

FP8: Data processing with Arduino or STM Nucleo

FC1: To make sure any meteorological event do not disturb the electronic system

FC2: To take the least place possible

FC3: To minimize the noise creating by the system in order to avoid disturbing the bees

FC4: To be able to create the system with the budget allowed by the school

FC5: To take into consideration the delivering time of the components

# Chapter II : Sensors : achievements and failures

# II.1 - Weight sensor

## II.1.1 How to connect four weight sensors?

For weight sensors, the main problem is to study their connection methods.

The structure of our weight sensors is four-wire and full bridge. We first considered using existing components to connect the four sensors. So we searched for available components and just found that the combiner can be used to connect weights sensors, but it is only applicable to three-wire and half bridge strain gauges. So this solution is not workable.

So, we solved this problem from the basic principle of the sensor.

### II.1.1.1 wheatstone bridge

A wheatstone bridge is a configuration of four resistors with a known voltage applied like this:

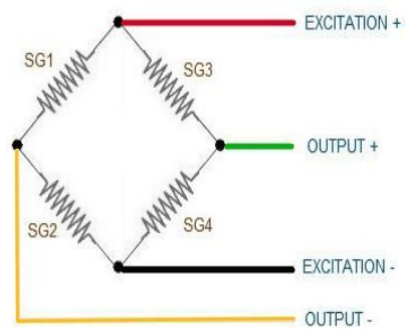
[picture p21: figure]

Figure II.1.1.1 wheatstone bridge

Vin is a known constant voltage, and the resulting Vout is measured. If R1/R2=R3/R4 then Vout is 0, but if there is a change to the value of one of the resistors, Vout will have a resulting change that can be measured and is governed by the following equation using Ohm's law:

We know that there is a circuit called Wheatstone bridge inside each sensor. When the sensor is stressed, the internal resistance of the circuit will change accordingly, which will cause the output voltage value.

Since the sum of the four sensor forces is the sum of the four voltage values, four sensors can be used in parallel.

### II.1.1.2 Using of Analog-To-Digital Converter-HX711

Due to the small resulting voltage, there is a large error if it is directly converted to actual weight. So we use HX711 analog-to-digital converter, it has two advantages to reduce the output error.

- Turn analog voltage into digital voltage to reduce electromagnetic interference
- linear gain in order to amplify the voltage

### II.1.1.3 Solution of connection

Therefore, we found two methods to build the connection.
Solution 1:
To save material costs, the number of components used should be reduced as much as possible. Because one HX711 can carry up to two weight sensors mostly, four sensors require two HX711. So, we use 2 HX711 AD module and 4 sensors.

The detailed connection method is that two sensors are connected in parallel to one HX711 by connecting the same color line on the breadboard, for example, the white line is connected with the white line, and the green line to green line. The following figure can shows the display described:

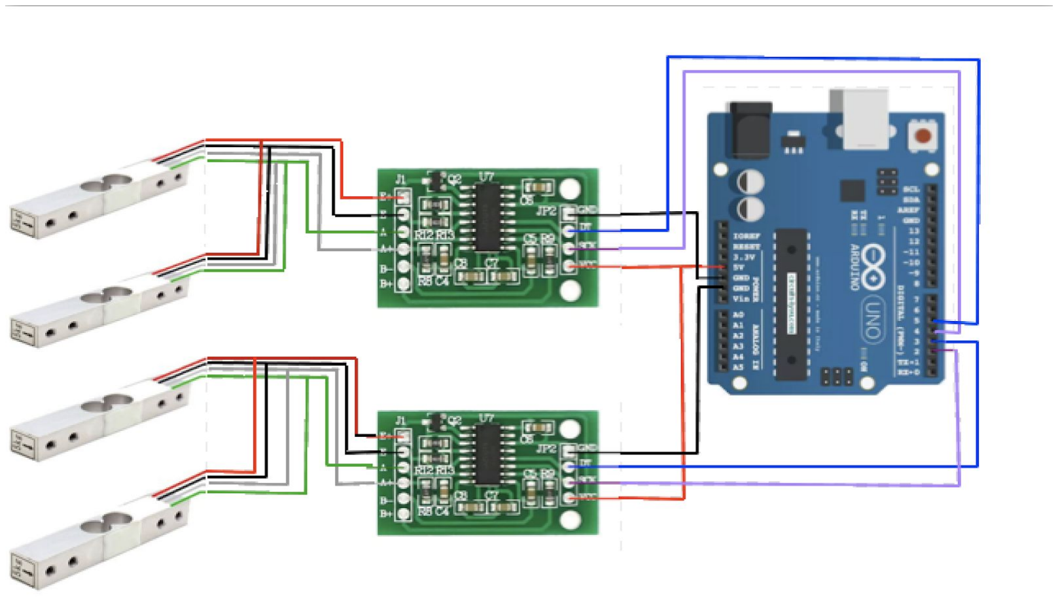
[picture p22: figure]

Figure II.1.1.3 Connection with 2 HX711 Solution 2:
If solution 1 is not workable, we can connect 4 sensors independently by using 4 HX711 AD module. Each sensor connected to the Arduino via a HX711. And the connection method is very simple, only need the corresponding pin of sensor and HX711 are connected.

## II.1.2 Relationship between the digital voltage and the actual weight

In order to get the actual weight of the object, we should find the relationship between the actual weight and the digital voltage after the HX711 amplification.There are already a large number of HX711 libraries that can be used on the network. Through studying one of the quality libraries, we found a linear relationship:

Y=aX+b
- Y: Value of current output voltage
- X: Actual weight
- a: Correction coefficient
- b: Offset of HX711

The problem is how to measure the 2 factors a and b. For this, we thought about two solutions.

Solution 1: Obtain the corresponding Y a nd X values from two objects of known weight, then solve a and b.
Solution 2: Starting from the HX711 library, the tare() function can automatically confirm the value of b. Simply use another object of known weight to obtain the corresponding Y and X values to find the value of a.

## II.1.3 Test protocol

### II.1.3.1 Sensor Force Study

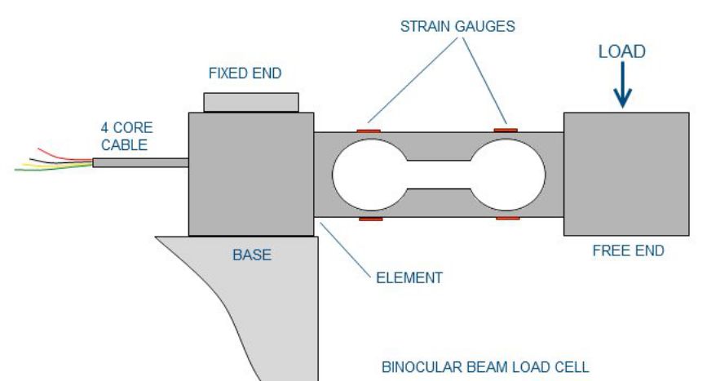
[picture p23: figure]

Figure II.1.3.1 Sensor force

The condition for the correct force of the sensor is that one end is fixed and the other end is pressurized. Before installation, we can only roughly estimate the performance of the sensor.

### II.1.3.2 Test procedure

Solution 1:
We choose the solution 1 of connection. We know that a HX711 AD analog-to-digital converter corresponds to a HX711 library variable, because there are two HX711, so we need to define two HX711 variables. Based on the existing code found, we can easily write the test code.

In order to ensure balanced force, the four sensors are placed at equal distances horizontally, and we use an electronic scale to measure an object, whose weight is applied to observe a and b readings. Since we connect two HX711 modules, each HX711 corresponds to a linear relationship (Y1=a1*X1+b1, Y2=a2*X2+b2). Under the condition of force balance of each sensor, we should ensure a1=a2 and b1=b2.

After establishing the connection, by observing the Arduino serial monitor, we found that the actual situation does not match the ideal situation(a1 ≠ a2, b1 ≠ b2).And there are big differences, such as b1_average = 4458000 and b2_average = 1641000 after 5 measurements.

Solution 2:
The second solution’s code is not much different from the previous one. Only four HX711 variables need to be defined to obtain four linear correspondences. Test in the same way, this time we can successfully make a1=a2, b1=b2, which provides guarantee for subsequent installation.

### II.1.3.3 Exploration of problem

It took us a long time to explore the cause of the problem. Under the condition of ensuring the balance of force again, we found that this kind of connection would cause great interference between sensors.

- Specific connection as shown below：

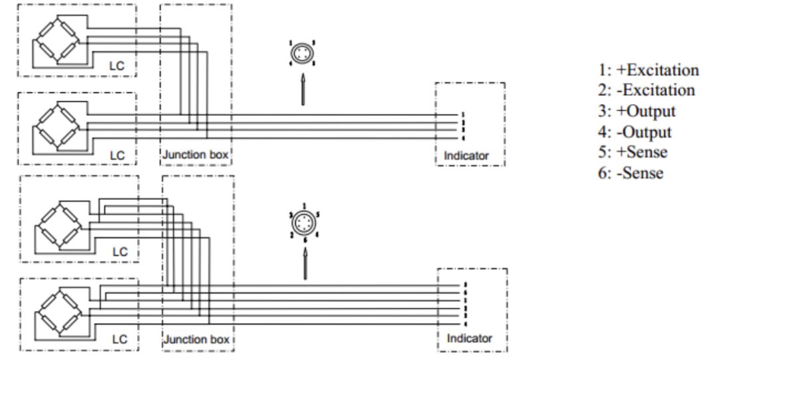
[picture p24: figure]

Figure II.1.3.3 Load cell cabling

Load cells should be electrically connected in such a way that the signal (output) lines, excitation (power supply) and sense (when present) lines are in parallel.

The above figures represent the two basic configurations, using four-wire ( sense ) load cells. With 4-wire extension cables the load cell output should be connected to pairs of diagonally opposite wires. Sometimes it is necessary to trim the output of each individual load cell to avoid corner load differences, which are caused by:

- The parallel connection. Each load cell will be loaded with the resistance of the other load cells. As a result, the individual load cell output tolerances will be increased by the individual output resistance tolerance.
- Unequal load distribution.

Trimming can be done by placing resistors or variable resistors into the excitation (Excitation trim) or output (signal trim) lines.

Reference: http://www.marco-iw.nl/file/1355354080.2319WAfreS/2%20Loadcell%20cabling.pdf

Because this shielding method is complicated, we tried the second solution to ensure independent connection between sensors and avoid its mutual influence.

# II.2 - Camera

According to the specification, the system must provide a camera so the user can see the actual beehive on the website, in real time.

## II.2.1 Pictures or live video stream ?

The ideal option would be to stream the live video of the beehive recorded by our camera, but it would need a lot of resources we cannot provide with our little website. We decided to use a camera that can send pictures with FTP protocol directly to our web server. Then, the PHP script would get the most recent take and make the html page display it.

## II.2.1 Implementation problems

The camera we chose is really easy to use on a common network. It can be accessed on a web browser and then configured. In reality, on Polytech’s network, it’s much harder to configure. The camera never succeed to connect to Polytech’s WiFi, it only worked through ethernet connection, but in real situation, the camera must connect to a WiFi as we can’t get an ethernet connection where the beehive will be. One of our member tried to fix this problem during more than 3 weeks, we then decided to give up on this feature for the moment.

# II.3 - Temperature acquisition

## II.3.1 Internal temperature

### II.3.1.a Choice of the sensor

As we have already explained on our previous research work, the temperature inside the hive is not uniform. We notice a higher temperature in the center and immediately above the cluster compared to the low part and in other empty portions of the hive. That is because warm air rises.
We then proposed to place two temperature sensor in the hive to have a more accurate measurement of the internal temperature. But we soon realized that we did not need to know the internal temperature in all parts of the hive. It is the cluster that matters.
That is why, our final decision was to place only one sensor right in the middle of the hive.
We used the DS18B20 sensor. Specifically, a pre-wired and waterproofed version of the sensor which is more handy for measuring something far away, or in wet conditions which is the case inside our hive.

### II.3.1.b Pin connection and wiring

Depending on the colours of the wires:

- Red (VCC) - VCC 5V of the Arduino/Nucleo board.
- Yellow (DATA) - Any digital pin (with a 4.7K resistor pulled high)
- Black (GND) - GND of the board.


Figure II.3.1 Implementation of the DS18B20 with an Arduino Board

## II.3.1 External temperature

Part of the specifications was to measure, in addition to the temperature inside the hive, the external temperature. Which is a good climate indicator influencing the activity of bees, especially their outings.
The sensor we wanted to implement for this acquisition was the BME280 because of its great accuracy in measurements and the additional information it provided on humidity and and atmospheric pressure.
Unfortunately, we did not implement this sensor on the hive since it was never delivered. We had another temperature sensor available (DHT11) but it was imprecise, especially for the humidity.

# II.4 Brightness sensor

## II.4.a Choice of the sensor

Besides the influence of the temperature on bees, we have explained how the brightness factor influence the outings of bees.

We chose the BH1750 sensor because it s suitable for obtaining the ambient light data and for its great performances regarding the types of measurements we want to make. It is possible to detect wide range of light intensity at high resolution.

We placed this sensor outside, on top of the hive in order to get the ambient light data.
The wiring of this sensor is very simple and can be found on our previous bibliographic report with all the details on its running and performances

## II.4.b Pin connection and wiring

GND - connected to the GND of the Arduino/Nucleo board. VCC - connected to the VCC 3.3V of the board.
ADDR - connected to the GND of the board.
SCL - connected to the Analog input 5 (A5).
SDA - connected to the Analog input 4 (A4).

Below is an example of an implementation of the sensor :


### Figure II.4.b Implementation of the BH1750 with an Arduino board

# II.5 Test protocol

These sensors being premade and coming from the market. We already have informations on theirs performances and limits. The tests we made were here to confirm the specifications of the products.

The DS18B20 was tested by putting another temperature sensor that we had available (the DHT11) and measuring at the same time, with both sensors, the temperature around the room: on the shaded part of the room and in front of the window where the sun was passing through. We also tested on cold bottle of water and on our skin. We noticed that the temperature acquired by both sensors was about the same with 2°C to 3°C difference due to the impreciseness of the DHT11 sensor.
We also submerged the DS18B20 in a glass of water and ran the tests above one more time to make sure of the waterproofness of the sensor. The results of the second test were the same as the previous one.

Since we did not have another brightness sensor to run a comparison test, the BH1750 was tested by acquiring multiple values of light levels from known environments. We therefore made the table below showing results from our sensor and from internet documentation.

Surfaces illuminated by | Illuminance (lux) - BH1750 sensor | Illuminance (lux) - Wikipedia
Starlight | 0 (inside a box, complete dark) | 0.0001
Room project lighting | 450 | 320 – 500
Full daylight (not direct sun) | 12,000 - 15,000 | 10,000 – 25,000
Direct sunlight | 90,000 - 115,000 | 32,000 – 100,000

We can see that the sensor’s results are accurate and reliable.

# II.6 Bee counter

According to our specifications, the bee counter was supposed to be made with proximity capacitive sensors. The goal was to design multiple tubes placed at the entrance of the hive. On the top and bottom part of each tube, a plate of metal would be placed to create a capacitance. When a bee goes through a tube, the capacitance value changes affecting the input signal and therefore indicating that a bee has passed.


Figure II.6.1 3D view of a bee counter example

We would also have created the hand made capacitance on both edges of the tubes in order to distinguish an entrance or an outing of the bees and therefore prevent a double counting which is incorrect.

The mere fact that the capacitance changes is not particularly useful. To actually perform capacitive touch sensing, we need a circuit that can measure capacitance with enough accuracy to consistently identify the increase in capacitance caused by the presence of the bee.

The main problem we faced was the small value of the capacitance.
We wanted the tubes to have an entrance so that only bees can come in and not hornets which are a threat to honeybees. In order to do that, the entrance of the tubes must be around 16 mm according to a bee size. With that constraint, the capacitance value we calculated with the following equation was around the picofarad.


Figure II.6.2 Parallel metal plate capacitor

The capacitance of flat, parallel metallic plates of area A and separation between them d.
ε permittivity of space and k relative permittivity of the dielectric material between the plates (k=1 for free space, approximately =1 for air).

With such a small value, we can’t exploit that data to perform any calculation to indicate the change of the input signal sent to the plates. In addition to that, since the entrances of the tubes are so small, and the system being based on the electric field between the plates, each tube could influence the one next to it.

After several week of research and trying to find a solution in order to use the small value of the capacitance, we chose to set aside the capacitive bee counter solution and try another type of counter, based on Infrared detection.
It consist on an IR LED and a phototransistor. The circuit used is simple and is shown below:


Figure II.6.3 Basic circuit for IR detection (M.Masson Arduino course)

We implemented this circuit on a breadboard in order to write the code that will count each passing of an object. Here we used our finger to emulate the crossing of a bee. We implemented this circuit in two identical copies to emulate, the edges of the tube so that we can differentiate when a bee goes in or out.
Since we had problems using two counters (one for each sensor) with the for loop in our code, we used the function millis() to get the time when a detection is made and then compare which sensor was triggered first.

The difficulty is to cover all the scenarios in our code which are many, for example, the first is to determine whether the bee is going in or out, if a bee goes through the first sensor but not the second, if two or more bees go through the sensors, if one bee goes in whilst another goes out, if its another insect…

Due to a lack of time and a lot of scenarios to cover, we unfortunately did not succeed on having an accurate counting. An additional work on this sensor would have probably shown some positive results regarding the counting, but it would not be precise regarding the scenarios mentioned above

# Chapter II : Send data to the website

# II.1 - What module and how to send data over internet ?

According to the project specifications, the system must be able to send the data collected by our sensors directly to a web server, so we can process it. There are many ways to do that. In our case, we firstly chose to use an WiFi module called ESP8266. This module can be wired to an Arduino card directly, but our tutor advised us to use a dedicated card that embeds directly a ESP8266, for more stability. But even with this type of card, the more the code was complicated, the less the module was stable, and we faced many crashes. Then, we made some research and decided to use the LoRa WiFi module ESP32 from Heltec, with OLED screen, because of its performances and stability. After some code adaptation, we saw that it was a good choice because it worked perfectly fine.

The code is pretty simple, as it simply makes the module connect to a WiFi host and send GET requests to a PHP script host on our website. The ESP32 receives data from the Arduino card and then send them. This was the first step of the web development of the project, be able to send and get data through the internet. The final goal is to store these data and display charts of each data type so we can see the evolution over time. The code is available in the dedicated section in annexe.

In fact, we had many problems to face. The first problem was to send our GET request through Polytech’s network. Indeed, this network is very secured and each device must log in with an account to be able to use the internet connection. But it was to complicated and unsecured to implement it in our code. We had to get a special access which would allow our device to bypass this authentication, by using its MAC address to authorize it to use the internet. So far, nothing complicated, but even with this bypass, our GET requests were unable to reach our website, even if our device could connect to the host. Then, we decided to not lose too much time on this part, and decided to use the connection from one of our phones to test if our system was working. Moreover, the delay to get responses from the IT service was a bit too long, and it would have stopped us in our progress.

The second problem was the web development itself. None of us was familiar with PHP so we had to learn on the job. We succeed to develop a test page to check if we get the data, but we haven’t be able to develop the final website with charts and data storage. Moreover, not having root access on the website made us wait from IT service even for simple tasks like creating a database. We decided to stay with our test page for the moment.
The PHP script is simple, it tests what data is received and then updates the files where data are written. This script is available in the dedicated section in annexe.

# II.2 - Test protocol

The first step is to test if the PHP script is able to get data and display them in a .html page. To do that, we can simply use a PC and send GET requests to our website. This way, we know exactly what data we send so we know what should be displayed on the website. This first step was very useful as the script wasn’t perfect at the first try, but we improved it and fixed the errors. The final step is to let the ESP32 send its own GET requests to the website, we added the code necessary to trace what the ESP32 was sending, and checked what was received by the website. This way we’ve been able to test and validate our website and the request sending of the ESP32.

# II.3 Security improvement

At the actual status of the project, the website works with HTTP. It works well for what we want to do but this protocol is not secured. Every request can be read by everyone, so everyone can know how we do our GET requests, so everyone can change what is displayed on the website. One solution would be to change the HTTP protocol by a HTTPS protocol, which encrypts the requests. We’ve included this security in our code and it worked but the school didn’t provide a website which worked with HTTPS so we had to get back to HTTP protocol.

# Chapter III : ESP32 and Arduino interfacing

This chapter will expose how the Arduino Uno and the ESP32 are interfaced, how do they communicate, and first of all why use 2 card.

# III.1 - Why use 2 cards ?

In this our, 2 cards are used : an Arduino Uno and an ESP32 embedded on a Heltec card. The reason is simple, we need that our system is as stable as possible, because it’s supposed to work all day long, we can’t have a system that crashes every hour and needs to be rebooted by the user. After discussion with our tutor about the ESP8266, we decided to use the ESP32 embedded on it’s own card.

# III.2 - Make them communicate

Now that there are 2 cards in our beehive, we need them to communicate. Indeed, the main role of the Arduino is to process data received by all our sensors, where the main role of the ESP32 is to send these data to the website. Then, we had to imagine a way to make them communicate in an efficient way so we can prevent errors. The simpler way to do that, was to create a special TX/RX protocol both cards can understand and process.

The operation is simple, we want our Arduino to send messages to the ESP32 which contains a data measured by a sensor. Indeed, each message will contain only one data, for example the temperature measured. The Arduino will send these data one after the other in loop, as strings of characters.
So now the Arduino is capable of sending data through a TX/RX transmission. But since the Arduino sends each data one after the other, how the ESP32 can detect the start of a message, and its end ? We decided to make the Arduino send a start character and an end character. This way, the message would be encapsulated and its start and its end would be identifiable by the ESP32.
One problem is still existing. The Arduino can send data, and the ESP32 can identify the start and the end of the message, but how can it detect which type of data is received ? Is it a temperature, a humidity ? It can’t know this at the moment. The solution we chose is the add another informative character, a data type character, that would make the ESP32 be able to know what data has been received.
Now our protocol is finally designed, and looks like this :


Figure III.2.1 Message example using our protocol

As it can be seen here, the message contains a temperature data, and its value is 21.3 degrees. Thanks to the code we implemented in both cards, we are able to make them communicate and understand each other through this specific protocol. The code is available at the end of this document for more details.

# III.3 - Test protocol

We’ll see in this part how we have tested and validated our protocol and its implementation in C. The operation is simple and divided in different step. We first need to test if the code works on each card.

For the Arduino, we need to check if the messages it sends are correct. We add the code necessary so we can get the message the Arduino is sending through USB connection with our PC. The Arduino IDE provides a serial monitor which allow us to receive these messages. We make su that the code will send a predetermined message so we are able to know what message we should receive through serial monitor. This part has been quickly validated as it is a simple task for the Arduino.

For the ESP32, we need to check if the message received has been correctly identified. We add the code necessary so we can fake the predetermined data reception and check if our algorithm processes it correctly. We use the serial monitor to check if the ESP32 identifies the start and end characters, the data type and finally the value sent. This part has been less quick to validate but we hadn’t that much problem, everything has been fixed quickly.

Now that our 2 modules embeds working algorithm, we have to connect them and see if it’s still working fine. We program the Arduino so it can send various data (with different data types) with fake value (for test purpose) and we connect it with the ESP32. We know exactly what the Arduino is sending through serial monitor, and we have to check if the ESP32 gets every data and processes it correctly. The main problem of this part was to find a good delay between each message because if we let the system run for a long time, it started to get corrupted data. After some test, we’ve been able to quickly find a perfect delay. We now can let the system run for hours without getting one error. The system is now tested and validated.

# Chapter IV : Physical implementation of the system

# IV.1 - Architecture


Here is the general Architecture of our project. Each square represents a function described in the first chapter of this report. This architecture is what the system will be at its final status.

At the moment the architecture of our system looks like this :

We can see that the system does not implement neither the camera nor the humidity sensors and pressure. But it implements the weight sensor, temperature, light and is capable of sending data to our website. For more details, please refer to the chapter VI.

# IV.2 - The board


Figure IV.2.1 Board

The board is divided in 3 parts. On the left of the picture, we have a little circuit that brings together all the power cable for our sensors (+5V and GND) and some resistors necessary in order to use the temperature sensor and our TX/RX communication between the Arduino and ESP32. Then, on the center of the board, we have our 4 HX711 necessary in order to interface our weight sensors with our Arduino. finally, on the right side we have the Arduino board which welcomes all the sensors.
We can see that everything is built to be replaced easily. Indeed, this connected hive is only a prototype at the moment, this is not a final state, so we’ve built everything to be easy to replace in case of change.

## IV.2.1 Intermediate circuit

Here is a detailed schematic for this side of the board. Like said just before, this circuit is here to power all the sensors and to implements necessary resistors.


Figure IV.2.1.1 Detailed schematic

For the detailed mapping of the sensors on the Arduino, please refer to the dedicated section in annexe.

# Chapter V : Project planning

As in any project, it is very important to have a planning during the lifecycle of our projects. Throughout the BeeConnect project, we tried to keep a record of all the tasks we have done during the sessions.
Before rushing to move ahead with execution or reporting results, we gathered all the tasks we needed to accomplish from the specifications we were given. Afterwards, we assigned each member of the team with two or three tasks to complete in an estimated time. Each member was free to set the timing and deadlines for their tasks.


Figure V.1 Final project planning

# Chapter VI : Actual project status

At the moment, most of the specifications are met, but not all of them. According to them, our system should collect data about the temperature, the humidity, the atmospheric pressure, the weight and finally the brightness. At the moment, the system is able to provide data about the temperature, the brightness and the weight. It doesn’t implement the 2 other sensors simply because all the input of the Arduino Uno are full. A simple solution would be to use an Arduino Mega, which provides more pins.
Concerning the data sending over internet, the system is fully operational. The main problem for us is the Polytech’s network because it filters too much things and it’s hard to bypass everything. Moreover, our website is able to receive these data, but we need to develop a website that could store these data and process them in order to display different charts. Indeed, at actual state, the website can only display the last data which has been received.
Concerning the use of the STM32, we had to find the librairies adapted from Arduino in order to use our sensors with this card. Almost every sensors’ libraries had been already adapted to this card but not the library of the DS18B20, the temperature sensor. We didn’t have the time to adapt it so we decided to get back on the Arduino.

Also, we were not able to deliver the bee counter. We spent a large amount of time on the capacitive plates sensor solution which turned out to be not suitable for the hive giving the dimensions of the counter and what we wanted to detect (i.e the bees). Our work on this first counter has cost us a lot of time which impacted negatively on the global planning of the project. Therefore, even if we had finally decided to focus on another implementation, based on infrared detection, we were not able to pass the tests and calibration of one sample of the counter, meaning one “theoretical tube entrance”.

Finally, we neglected one aspect in the planning which is the physical implementation of the entire system on the hive. Our focus was more on trying to make the sensors work and the website up. We had several “side tasks” to accomplish in order to set up the smart hive such as: organizing all the circuitry on one board and designing a wood box that would later contain the Arduino board and the circuitry, placing the sensors in the right places, insulating wires, jumpers, sensors, holes on the hives…

This slackness taught us to be more careful about these side tasks in the future and to not neglect them as they are the difference between a prototype and the final product.

# Conclusion

This report is a work in progress of an entire semester on the BeeConnect project. Our goal was to take a simple beehive and turn it into a smart hive that can provide users with information regarding its health and status.
We started by working on a bibliographic research in order to get more familiar with the project, setting the goals and exploring multiple solutions to chose the most suitable for the hive.

After that, we tackled the practical aspect of the development of our system which had many learning outcomes in both technical and management aspects.
Working in full autonomy allowed us to have a more precise idea of an engineer job, and a better understanding of the lifecycle of a project and the importance of planning and monitoring the tasks accomplished.

Finally, we wanted to express more our interest in the BeeConnect project and the desire of some of the team members to continue its development next year and achieve the specification we were not able to meet.

# Annexes

# I - Sensors mapping on Arduino

BH1750

SCL -> SCL
SDA -> SDA
HX711
| Pin number | Pin number | Pin number | Pin number
DT (Green) | 5 | 6 | 7 | 8
SCK (White) | 9 | 10 | 11 | 12

The white wire from a weight sensor goes to the pin A+. The green wire goes to the pin A-. VCC on E+, GND on E-.

## DS18B20

Data (blue) connected to intermediate circuit to the two parallel mounted resistors of 10K ohm (blue wire). The second blue wire goes to the pin 4 on the Arduino.

## TX/RX Arduino/ESP32

Yellow wire goes from pin 3 (Arduino) to the intermediate circuit, the pin closer to GND rack. A second yellow cable goes from the pin above the first one, to the pin 34 of the ESP32.

# II - Embedded software on Arduino


# III - Embedded software on ESP32



# IV - PHP script




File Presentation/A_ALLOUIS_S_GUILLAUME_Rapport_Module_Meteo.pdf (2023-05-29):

Projet Électronique - Station météo | Pour le 01/06/2023

# Projet Électronique Station météo


A.ALLOUIS & S.GUILLAUME - ITII EII 4 | - | 1 / 14

## Table des matières

1. Introduction : Présentation du projet | 3
2. Module Météo | 4
3. Planning du projet | 5
4. Déroulement du projet | 6
1. Amorce du projet | 6
2. Programmation des modules et leur fonctionnement | 7
2.1. Le pluviomètre | 7
2.2. La girouette | 7
2.3. L'anémomètre | 9
2.4. Le capteur BME 280 | 9
2.5. Le capteur TSL 2591 | 10
2.6. Le protocol LoRa | 11
5. Les difficultés et solutions trouvées | 12
1. L’alimentation des modules | 12
2. La Girouette | 12
3. Le low power mode | 13
6. Statut du projet et les explorations pour l’année suivante | 14
7. Conclusion | 14

## 1. Introduction : Présentation du projet

Polytech accueille plusieurs ruches situées sur les toits de l’école. Ces ruches servent à préserver à l’échelle locale les abeilles et l’environnement.

Ces ruches sont aussi l’occasion pour les élèves en classe d’ingénieur de travailler sur des projets d’amélioration du dispositif en alliant de l’électronique et de l’informatique. Diverses idées d’améliorations sont étudiées, dont certaines novatrices. Ces idées sont décrites ci-dessous :

Les abeilles sont régulièrement menacées par des parasites : les frelons et les varroas. Le but premier est de les éliminer.

Dans le cas des frelons, un dispositif laser avec localisation et visée du frelon est actuellement à l’étude.

Pour éliminer les varroas, deux options sont possibles. La première idée est de les étouffer en “polluant la ruche” de carbone à quantité suffisante pour les tuer sans asphyxier les abeilles. La seconde est un système de ventilation permettant la diffusion globale de la chaleur dans tout l’espace confiné de la ruche.

Une fois le varroa éliminé, celui-ci tombe au fond de la ruche. Un tapis roulant situé sous la ruche, récupère les varroas. Muni d’une caméra, une détection du varroa est effectuée. De plus, le nombre de varroa est compté et permettra par la suite de vérifier le bon fonctionnement des méthodes d'éradication.

Avec les réseaux LoRa, GSM et WiFi, toutes les informations détectées à l'intérieur ou bien à l'extérieur de la ruche sont envoyées à l’utilisateur. Pour les données extérieures, on y retrouve les informations météorologiques renvoyées par le module météo.

Afin d’automatiser le fonctionnement de nombreux équipements, une alimentation par batterie est requise.

Les différentes tâches représentent 6 projets à réaliser en binômes et 1 en quartet.

Notre binôme a choisi de réaliser le module météo. Dans le suite de ce rapport, une présentation du module et de son fonctionnement sera faite. On retrouvera notre organisation et notre répartition des tâches pour mener à bien notre projet. Ensuite, nous rentrerons plus en détail dans le déroulement de nos tâches. Nous ferons un point sur nos difficultés rencontrées et sur les solutions apportées. Et enfin, nous ferons un point sur l'état actuel de notre travail.

## 2. Module Météo

Composition du module météo

- un anémomètre permettant la mesure de la vitesse du vent,
- une girouette pour donner la direction du vent,
- un pluviomètre afin de donner le taux de précipitations,
- un capteur BME/BMP280, composé de :
- un détecteur d’humidité pour donner un pourcentage d'humidité,
- un thermomètre pour la température,
- un capteur de pression atmosphérique,
- un capteur TSL 2591, composé de :
- un luxmètre pour la luminosité.

Objectif

Envoyer une trame LoRa complète de la forme suivante :

type | adresse mac de l’ESP | pluviomètre | anémomètre | girouette | pression (16bit)
| humidité | luminosité | température | batterie | checkbytes

Les moyens

Un lien github ouvert par l’équipe précédente nous a été restitué avec le code global, les documentations des composants et le powerpoint de présentation.

Nous disposons également d’une carte expérimentale intégrant le microcontrôleur ESP32 et de tous les outils de mesures nécessaires

## 3. Planning du projet

Le projet était composé de 21 séances de 3 heures 30 réparties entre septembre 2022 et avril 2023.

Tableau représentant la répartition des tâches et le temps passé sur chaque tâche.

Séance | 1 | 2 | 3 | 4 | 5 | 6 | 7 | 8 | 9 | 10 | 11 | 12 | 13 | 14 | 15 | 16 | 17 | 18 | 19 | 20 | 21
Date | 01/ 09 | 02/ 09 | 09/ 09 | 15/ 09 | 03/ 10 | 13/ 10 | 28/ 10 | 25/ 11 | 01/ 12 | 09/ 12 | 20/ 12 | 06/ 01 | 19/ 01 | 10/ 02 | 17/ 02 | 16/ 03 | 23/ 03 | 28/ 03 | 06/ 04 | 20/ 04 | 27/ 04

Lecture des documentations

Compréhension des codes

Codage du Pluviomètre

Codage de l'Anémomètre

Codage de la Girouette

Codage de la Trame LoRa

Codage BME & TSL

Makefile
Groupement des périphériques

Ajout de LoRa au groupement

Codage de l'Alimentation

Interruption & Mise en veille

Ajout de l'Alimentation au groupement

Ajout du Deep Sleep au groupement

Gestion des interruptions

Présentation du Projet

Legende

Ambre
Solène
Commun

## 4. Déroulement du projet

### 1. Amorce du projet

Lors de la première séance, nous avons dû nous mettre d'accord avec les autres groupes et choisir le projet qui nous intéressait le plus. S'ensuivant, nous avons pu récupérer les documentations techniques correspondantes aux équipements à utiliser, de plus, nous avons reçu la présentation globale sur les attendus du projet.

Pour démarrer le projet convenablement, nous avons dû installer l’environnement ainsi que les bibliothèques liées à L'ESP 32 et aux différents modules. Une fois l'environnement mis en place, nous avons testé le code fourni par l’équipe précédente. Malheureusement, ce code manquait de description et les tests ont été non concluants. Nous n’avons pas pu valider son fonctionnement.

Nous avons créé notre lien Github, organisé nos repositories et ajouté nos cahiers de suivis individuels en langage markdown.

Nous avons continué, les séances suivantes, après avoir pris connaissance des accomplissements déjà effectués l’année précédente, à tester le code existant, sans succès. le code ne compile pas. Nous avons décidé de tout recommencer à zéro.

Pour faciliter le développement du projet, nous avons commencé par des codes simples pouvant être testés individuellement. Nous avons d’abord développé un code vérifiant la bonne compilation de la carte en faisant clignoter la Led.

Pour démarrer le projet, nous avons toutes les deux travaillé sur le pluviomètre pour nous donner un premier aperçu sur le temps et sur la structure des codes.

Nous nous sommes ensuite divisées les différents modules à coder :

- Ambre :
- L'anémomètre,
- Les capteurs BME 280 et TSL 2591
- Solène :
- La girouette
- Le protocol LoRa

### 2. Programmation des modules et leur fonctionnement

### 2.1. Le pluviomètre


Un interrupteur est activé par un aimant qui est situé dans la bascule. Quand l'eau rentre dans le pluviomètre, cela active la bascule. Nous pouvons donc mesurer une certaine quantité d'eau en fonction du nombre de bascules.

A chaque interruption, il y a 0.2794 mm de pluie supplémentaires

La valeur en mm est relevée et ajoutée dans la trame LoRa.

### 2.2. La girouette


La girouette est composée de 8 résistances + interrupteurs en série qui s’ouvrent et se ferment selon la direction du vent et grâce à un aimant interne. Ce processus permet le changement de la tension fournie à l’ESP 32. Chaque position renvoie une tension différente nous permettant ainsi de déduire la direction du vent. La girouette peut renvoyer en tout 16 valeurs différentes ( La direction peut se situer entre la position de deux résistances. Alors les deux résistances se ferment simultanément.)

Un entier correspondant à la position est relevé et ajouté dans la trame LoRa.


Le schéma ci-joint montre
l'arrangement de l'interrupteur et de la résistance. Les valeurs de résistance pour les 16 positions possibles sont indiquées dans le tableau.

Les valeurs de résistance pour les positions situées entre celles indiquées dans le schéma sont le résultat de la connexion en parallèle de deux résistances adjacentes lorsque l'aimant de la palette active simultanément deux interrupteurs.


Note : Il faut faire attention au terme de direction du vent. La direction du vent est en fait l'origine du vent ( et non la direction vers laquelle il souffle ).

Un exemple concret : si le vent souffle vers le sud, alors le vent vient du nord. L'information qui sera énoncée dans un bulletin météo sera donc l’origine du vent. Un second exemple : Si le vent souffle vers le sud-est, son origine sera le nord-ouest.

### 2.3. L'anémomètre


L'anémomètre fonctionne à l'aide d'un interrupteur activé par un petit aimant. Il suffit de compter le nombre d’interruptions. Les interruptions correspondent au nombre de tours réalisés.

Un vent de 2,4 km/h cause une interruption par seconde.

Par un produit en croix, on en déduit donc la vitesse du vent en fonction du nombre d’interruptions.

La valeur en km/h de la vitesse du vent est relevée et ajoutée dans la trame LoRa.

### 2.4. Le capteur BME 280


Le capteur BME280/BMP280 est un capteur de pression, de température et d'humidité. Le capteur BME280 mesure ces trois paramètres environnementaux de manière précise et les fournit sous forme de données numériques exploitables.

Voici comment fonctionne le capteur BME280/BMP280 :

- Pression : Le capteur utilise le principe de détection de la pression atmosphérique pour mesurer la pression environnementale. Il est doté d'un élément sensible à la pression intégré qui réagit aux variations de pression.

Ce capteur mesure la pression relative par rapport à la pression atmosphérique standard au niveau de la mer.

- Température : Le capteur BME280/BMP280 dispose également d'un capteur de température intégré. Il utilise une thermistance (résistance qui varie avec la température) pour détecter les changements de température ambiante. La résistance de la thermistance est mesurée et convertie en une valeur de température numérique.
- Humidité : Pour mesurer l'humidité, le capteur utilise un capteur capacitif intégré. Ce capteur mesure la capacité électrique d'un matériau sensible à l'humidité. Lorsque l'humidité change, la capacité électrique change également, ce qui permet au capteur de déterminer le taux d'humidité ambiant.

Le capteur communique via un bus de communication standard tel que le bus I2C et le bus SPI.

La valeur en Pascal pour la pression, la valeur en degrés celsius pour la température et la valeur en pourcentage pour l'humidité sont relevées et ajoutées dans la trame LoRa.

### 2.5. Le capteur TSL 2591


Le capteur TSL 2591 est un capteur de lumière ambiante numérique précis. Le TSL 2591 mesure la lumière ambiante dans une large plage de spectre et fournit des données numériques exploitables.

Voici comment fonctionne le capteur TSL 2591 :

- Capteurs de lumière : Le capteur TSL 2591 comprend deux types de capteurs de lumière : un capteur de lumière visible (lumière dans la plage de spectre visible) et un capteur de lumière infrarouge (lumière dans la plage de spectre infrarouge).

- Photodétecteurs : Chaque capteur de lumière comprend un photodétecteur sensible à la lumière. Lorsque la lumière atteint le capteur, le photodétecteur convertit la lumière en courant électrique proportionnel à l'intensité lumineuse.
- Amplification du signal : ce qui permet d'améliorer la sensibilité du capteur et de détecter des niveaux de lumière plus faibles.
- Conversion analogique-numérique (CAN) : Les signaux amplifiés sont ensuite convertis en valeurs numériques. Les valeurs numériques représentent l'intensité de la lumière détectée par les capteurs.
- Calcul des mesures de lumière : Ces mesures permettent d'évaluer précisément l'environnement lumineux ambiant.

Il communique via un bus de communication standard tel que le bus I2C et le bus SPI.

La valeur en lux pour la luminosité est relevée et ajoutée dans la trame LoRa.

### 2.6. Le protocol LoRa

Le protocole LoRa (Long Range) est une technologie de communication sans fil basse consommation et longue portée.

Le protocole LoRa utilise une modulation appelée "modulation de spectre étalé". Cette modulation permet de transmettre des signaux sur une large plage de fréquences tout en étalant le spectre du signal sur une plus grande bande passante. Cela rend la transmission plus résistante aux interférences et aux atténuations du signal.

Le protocole LoRa utilise la bande de fréquence 868 MHz (fréquence européenne). Cette fréquence plus basse offre une meilleure pénétration des obstacles et une portée plus étendue par rapport aux fréquences plus élevées utilisées par d'autres technologies sans fil.

Le protocole LoRa est adapté à diverses applications IoT telles que la surveillance environnementale, la gestion des ressources, les systèmes d'irrigation, le suivi des actifs, etc. En raison de sa longue portée et de sa basse consommation d'énergie, il est particulièrement adapté aux déploiements à grande échelle et aux zones où l'accès aux réseaux cellulaires est limité.

Cette technologie est la plus adaptée à notre système étant donné que nous devons communiquer peu d'informations à une fréquence faible. Notre système est positionné à l'extérieur et doit communiquer avec une application distante.

## 5. Les difficultés et solutions trouvées

### 1. L’alimentation des modules

Lors du téléversement du code du pluviomètre, nous avons constaté qu’il ne détectait pas les fronts montants. Avec l'aide de M. Peter, de l'oscilloscope et du schéma, nous avons compris que l’alimentation fournie par le port USB était différente à celle relevée avec l'oscilloscope. Pour apporter l’alimentation nécessaire à V+, il fallait débloquer des transistors afin de les rendre passants.

Pour cela, avant de passer aux autres composants, il faut ajouter dans notre programme la pin MEASURE et la mettre à l'état HIGH.

### 2. La Girouette

Une fois le code de la girouette développé, nous n’arrivions pas à le téléverser. Il est apparu que le problème venait du fait que les mesures de tensions prises par l’ESP 32 sont instables et se situent dans un intervalle très petit. Pour améliorer l’efficacité de la prise de mesure, nous avons revu le montage de la carte.

Au lieu de continuer sur l’idée d’un pont diviseur de tension non fonctionnel car la tension d’entrée étant de base instable, nous avons remplacé la résistance principale par un générateur de courant.


Pour le générateur de courant, nous avons choisi le LM334DT que nous avons programmé pour générer un courant de 0,01 mA (La résistance équivalente maximale de la girouette étant de 120K).

Une fois que nous avons dessiné sous Eagle et soudé sur un PCB imprimé le montage présenté ci-dessus sur la carte, nous avons récupéré des valeurs stables et cohérentes. Il nous a ensuite suffit d’écrire un code récupérant la valeur mesurée et renvoyant la direction du vent.

### 3. Le low power mode

Une fois que nous avons réussi à générer une trame LoRa renvoyant toutes les valeurs récupérées par nos outils de mesure, il a fallu nous intéresser à consommer le moins possible.

Pour ceci, nous avons regardé les différents modes de low power proposés par la bibliothèque de l’ESP32. Le plus intéressant en termes de consommation est le deep sleep qui consomme 0,1mA au lieu d’avoir jusqu’à 60 mA en mode actif.

Le concept du deep sleep nous a demandé à revoir notre code en profondeur. Désormais, l’ESP32 reste inactif pendant 15 minutes et ne se réveille que s’il pleut durant cet intervalle. Lorsqu’il est réveillé, il prend le reste des valeurs et envoie la trame LoRa.

## 6. Statut du projet et les explorations pour l’année suivante

Nous estimons que nous touchons au but de ce projet. Selon nous toutes les tâches ont été prises en compte et réalisées.

Seulement, lors de la dernière séance, nous avons relevé une erreur lors du réveil de l'ESP 32 provoque par le pluviomètre. Lors de la première phase de réveil de l’ESP 32, tout se déroule correctement. Quand la seconde phase commence, après une seule interruption provoquée par le pluviomètre. L’ESP 32 se retrouve interrompu à l'infini par le pluviomètre.

De plus, après avoir fait de nombreuses modifications sur la carte, il serait nécessaire de réaliser un nouveau schéma de la carte. Ce nouveau schéma nous permettra de créer une nouvelle carte qui pourra être définitivement montée à proximité des ruches.

## 7. Conclusion

Pour conclure, ce rapport présente le projet Arduino réalisé par notre binôme visant à créer une station météo connectée utilisant le protocole LoRa pour la transmission des données. Notre objectif était de relever des mesures précises, puis de les transmettre de manière efficace sur de longues distances avec une consommation d'énergie réduite.

L'intégration de ces composants dans notre projet Arduino a été réalisée avec succès. Nous avons développé un code qui a permis de collecter les données de notre module météo, de les traiter et de les transmettre via le protocole LoRa.

En travaillant en binôme, nous avons pu mettre à profit nos compétences et nos connaissances pour mener à bien ce projet. La collaboration étroite entre nous a favorisé un échange d'idées, une répartition des tâches et une résolution efficace des problèmes rencontrés.

Enfin, ce projet Arduino de station météo connectée a été une expérience enrichissante et réussie. Il a permis d'acquérir des compétences techniques, de comprendre le fonctionnement du protocole LoRa et de réaliser une application pratique dans le domaine de l'IoT.

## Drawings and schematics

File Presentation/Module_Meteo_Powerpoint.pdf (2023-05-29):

# Le module

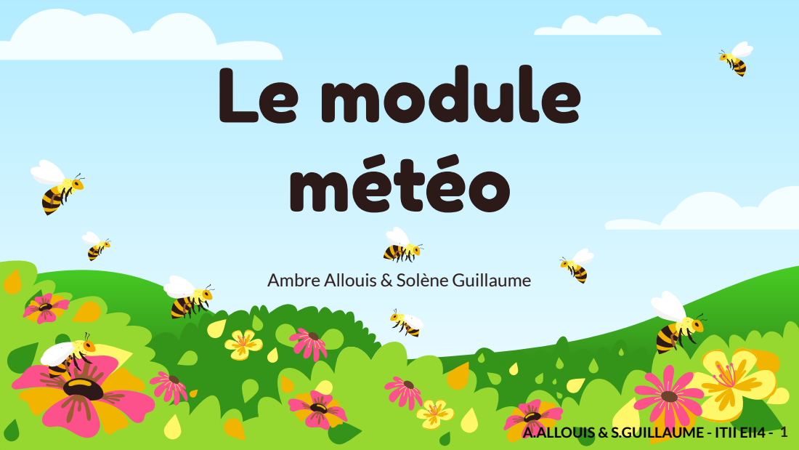
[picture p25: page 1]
météo

Ambre Allouis & Solène Guillaume

A.ALLOUIS & S.GUILLAUME - ITII EII4 - 1

# Sommaire

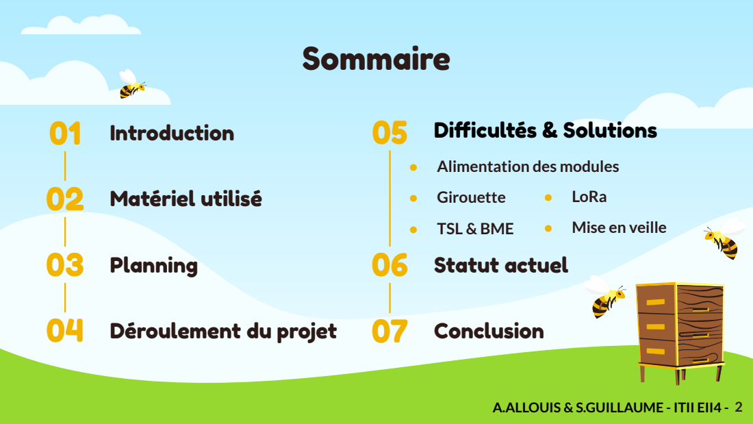
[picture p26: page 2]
Planning; Introduction; Matériel utilisé; Conclusion; Difficultés & Solutions; Statut actuel; ● Girouette; ● TSL & BME; ● LoRa

● Alimentation des modules

● Mise en veille

Déroulement du projet

A.ALLOUIS & S.GUILLAUME - ITII EII4 - 2

# Déroulement du Projet

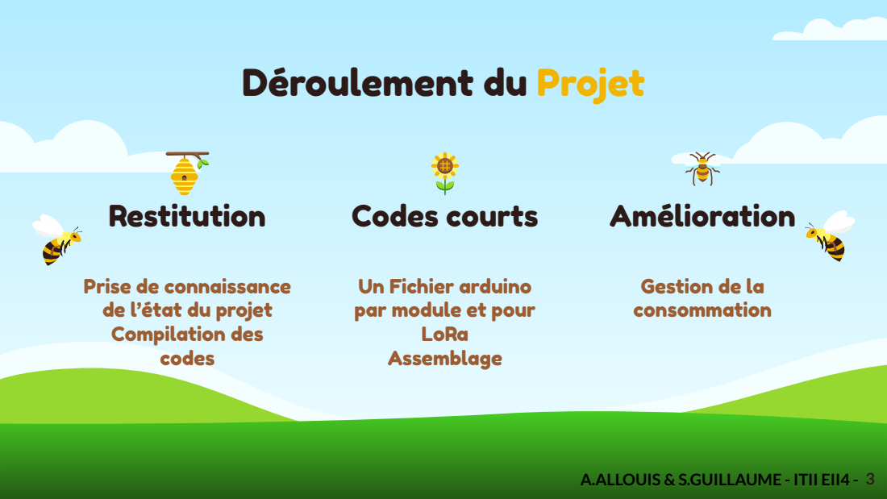
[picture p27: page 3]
Restitution; Codes courts; Amélioration

Prise de connaissance
de l’état du projet
Compilation des
codes

Un Fichier arduino
par module et pour
LoRa
Assemblage

Gestion de la
consommation

A.ALLOUIS & S.GUILLAUME - ITII EII4 - 3

# Présentation du matériel

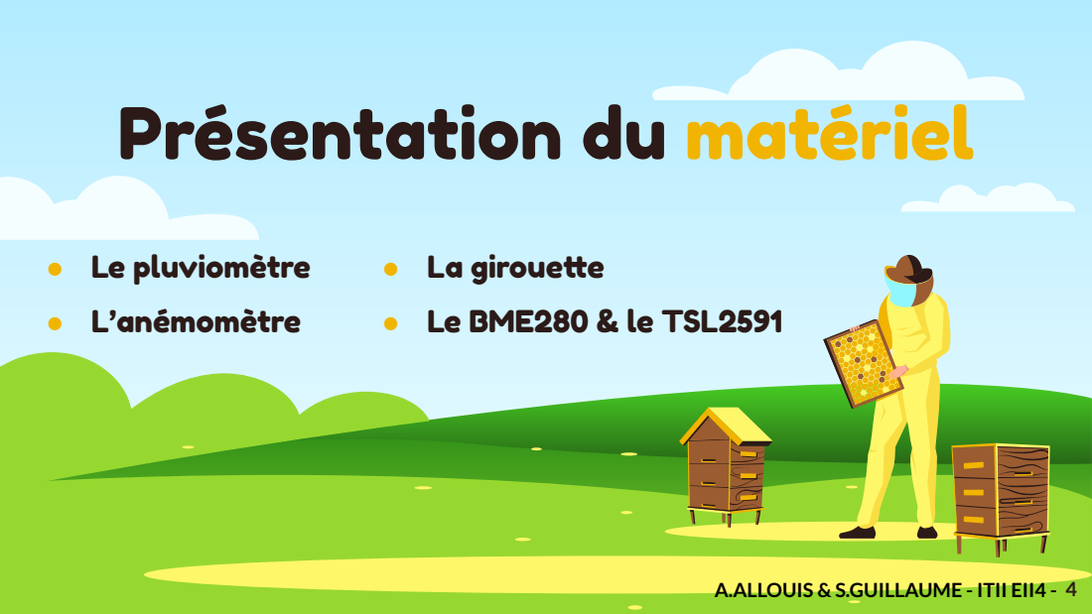
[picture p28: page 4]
● Le pluviomètre; ● L’anémomètre; ● La girouette; ● Le BME280 & le TSL2591

A.ALLOUIS & S.GUILLAUME - ITII EII4 - 4

# Le pluviomètre

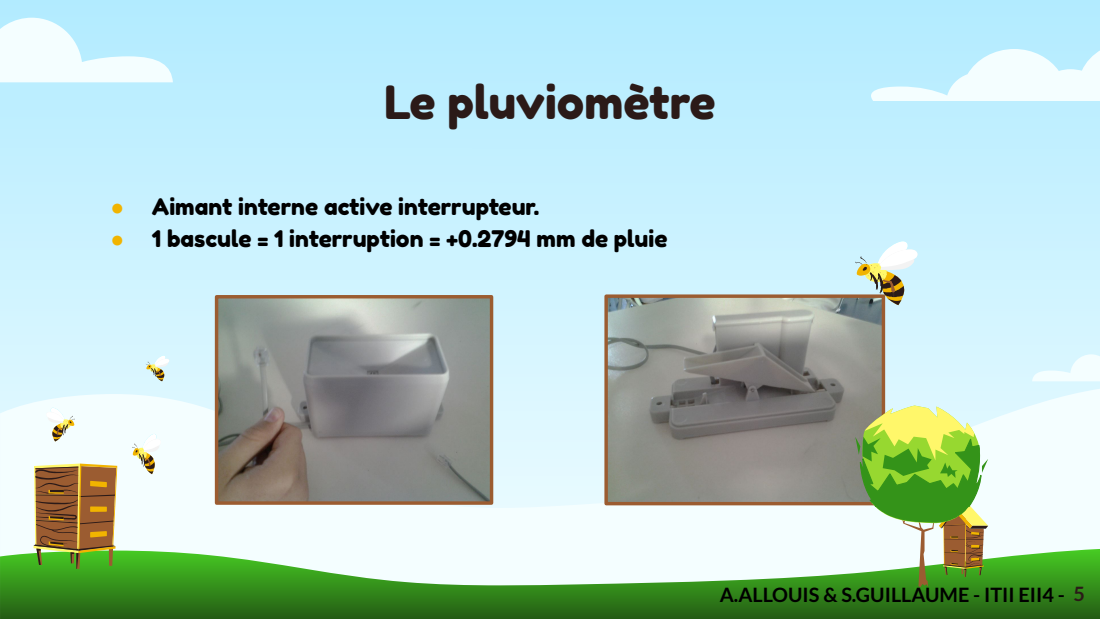
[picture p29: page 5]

● Aimant interne active interrupteur.
● 1 bascule = 1 interruption = +0.2794 mm de pluie

A.ALLOUIS & S.GUILLAUME - ITII EII4 - 5

# L’anémomètre

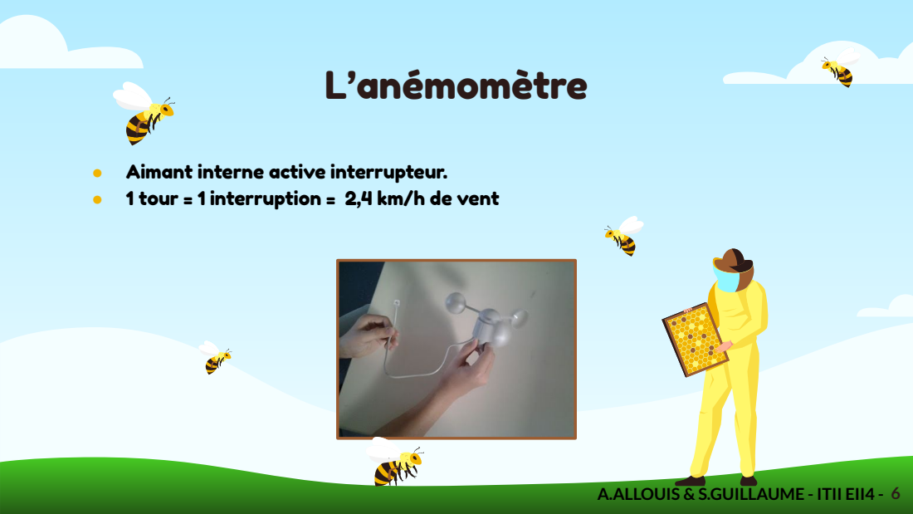
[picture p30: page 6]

● Aimant interne active interrupteur.
● 1 tour = 1 interruption = 2,4 km/h de vent

A.ALLOUIS & S.GUILLAUME - ITII EII4 - 6

# La girouette

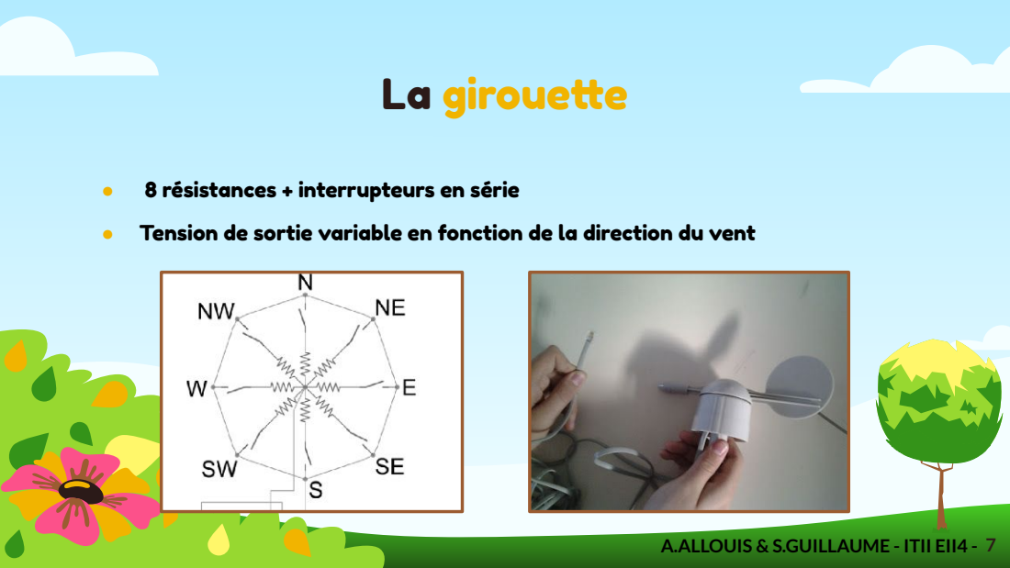
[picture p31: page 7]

● 8 résistances + interrupteurs en série
● Tension de sortie variable en fonction de la direction du vent

A.ALLOUIS & S.GUILLAUME - ITII EII4 - 7

# BME280 et TSL2591

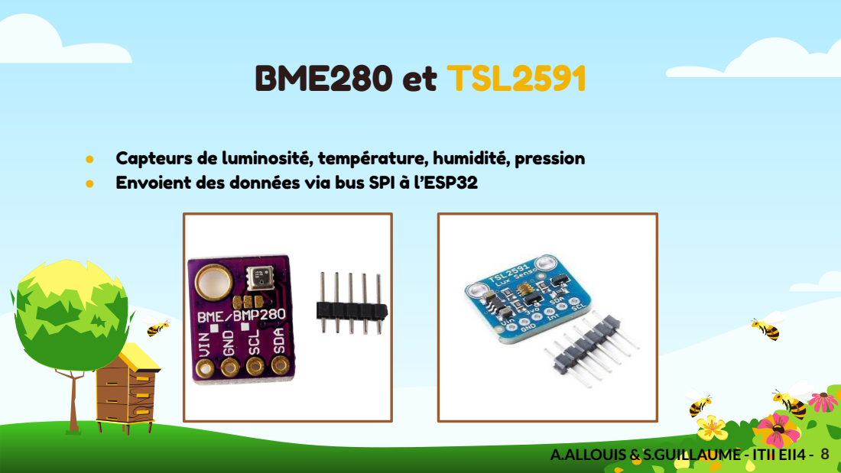
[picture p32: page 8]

● Capteurs de luminosité, température, humidité, pression
● Envoient des données via bus SPI à l’ESP32

A.ALLOUIS & S.GUILLAUME - ITII EII4 - 8

# Planning 1/2

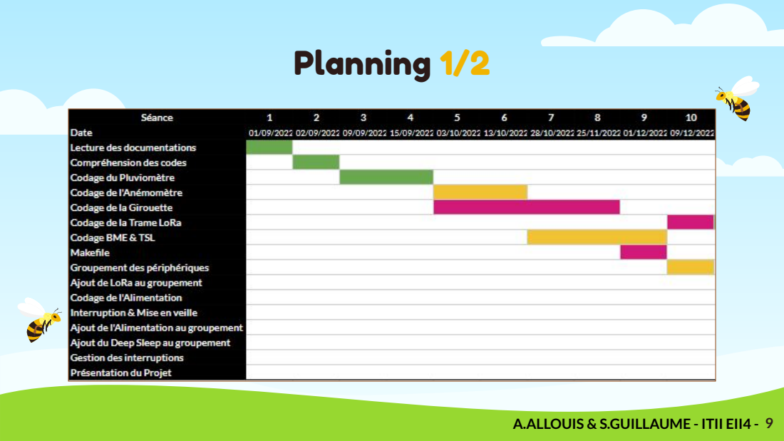
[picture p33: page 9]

A.ALLOUIS & S.GUILLAUME - ITII EII4 - 9

# Planning 2/2

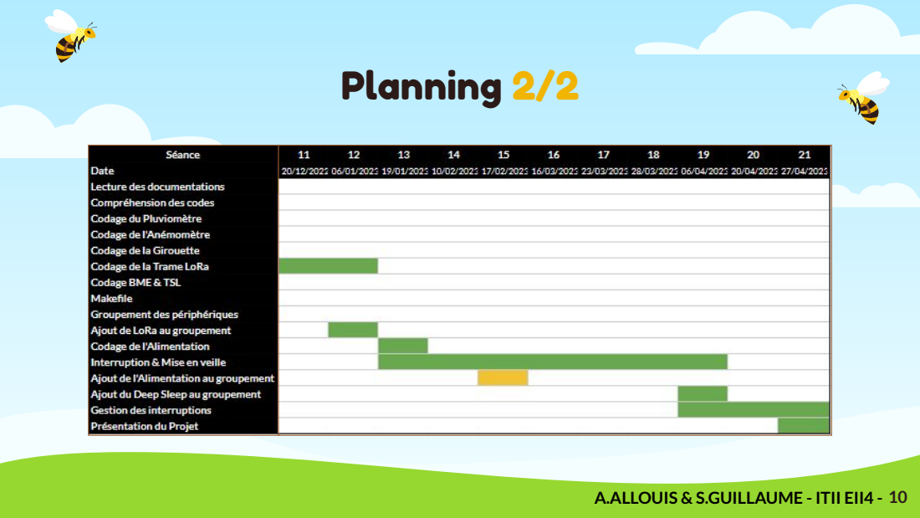
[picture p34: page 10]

A.ALLOUIS & S.GUILLAUME - ITII EII4 - 10

# Difficultés et Solutions

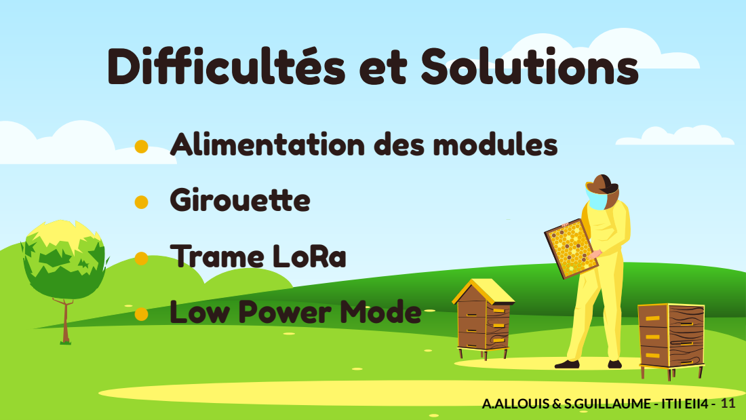
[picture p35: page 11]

● Alimentation des modules
● Girouette
● Trame LoRa
● Low Power Mode

A.ALLOUIS & S.GUILLAUME - ITII EII4 - 11

# Alimentation des modules

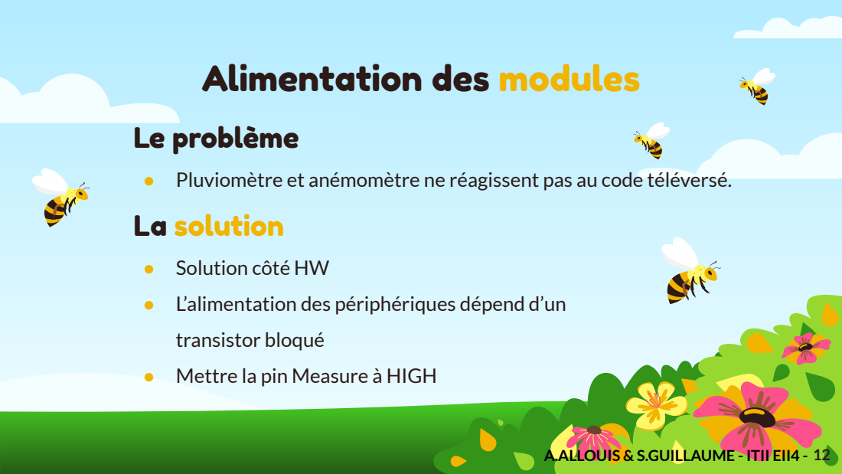
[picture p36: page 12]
Le problème

● Pluviomètre et anémomètre ne réagissent pas au code téléversé.
La solution

● Solution côté HW
● L’alimentation des périphériques dépend d’un
transistor bloqué
● Mettre la pin Measure à HIGH

A.ALLOUIS & S.GUILLAUME - ITII EII4 - 12

# Girouette

# Le problème


● Le code parait bon mais la girouette renvoie des valeurs
très instables
La solution

● Solution côté HW
● Résistance du pont diviseur de tension remplacée
par un générateur de courant → tension fixe
● Valeurs cohérentes et stables

A.ALLOUIS & S.GUILLAUME - ITII EII4 - 13

# Trame LoRa

● Quantité d’eau; ● Température; ● Luminosité; ● Pression x2; ● Humidité; ● Tension

Typage fonctions et données
Composition :
● Adresse MAC
● Vitesse du vent
● Direction du vent

A.ALLOUIS & S.GUILLAUME - ITII EII4 -

# Low Power Mode


Le problème
● Le réveil du Deep Sleep induit une chute de
tension qui perturbe les mesures
La solution
● Alimentation de la carte en 5V externe sur le V+
● Dysfonctionnement du pluviomètre
● Pluviomètre maintenant alimenté par VCC.

A.ALLOUIS & S.GUILLAUME - ITII EII4 - 15

# Statut actuel

→ Estimation : 1 cours

● Rapport de Projet
● Interruptions Pluviomètre
● Carte électronique

A.ALLOUIS & S.GUILLAUME - ITII EII4 - 16

# Conclusion

● Connaissances Hardware; ● Gestion consommation; ● Esprit critique

● Fin du projet

● Découverte Technologie LoRa

A.ALLOUIS & S.GUILLAUME - ITII EII4 - 17


Merci pour votre
attention !

Ambre ALLOUIS & Solène GUILLAUME

A.ALLOUIS & S.GUILLAUME - ITII EII4 -

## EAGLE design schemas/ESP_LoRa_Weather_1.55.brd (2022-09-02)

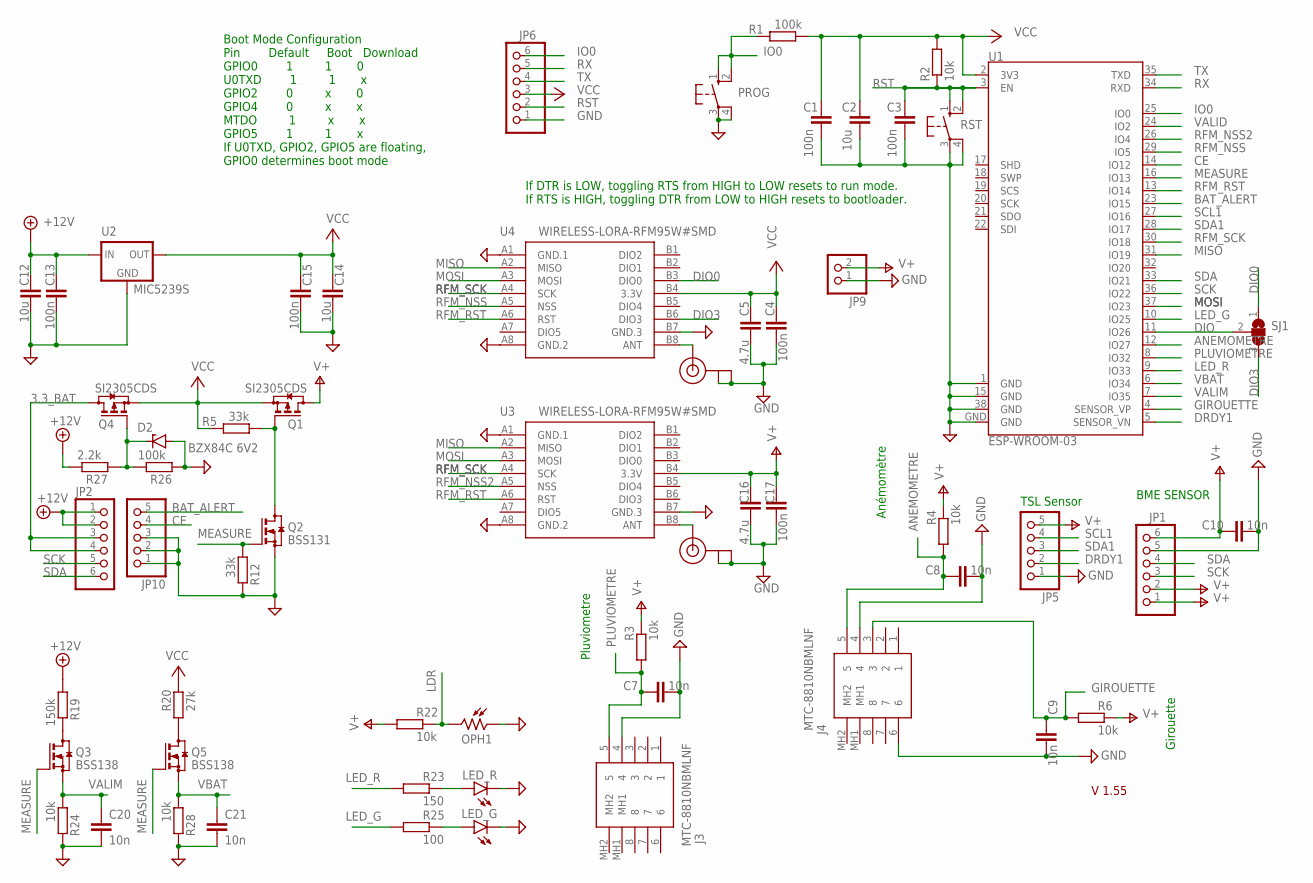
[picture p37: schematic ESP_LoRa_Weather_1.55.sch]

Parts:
C1, C3, C4, C13, C15, C17: 100n; C1206
C2, C12, C14: 10u; C1210
C5, C16: 4.7u; C1210
C7, C8, C9, C10, C20, C21: 10n; C1206
D2: BZX84C 6V2; TO236
J1, J2: U.FL
J3, J4: MTC-8810NBMLNF; MTC8810NBMLNF
JP1, JP2, JP6: PINHD-1X6; 1X06
JP5, JP10: PINHD-1X5; 1X05
JP9: PINHD-1X2; 1X02
LED_G: LEDSMT1206; 1206
LED_R: LEDSMT1206; 1206
OPH1: VT93N2; VT900
PROG: 10-XX; B3F-10XX
Q1, Q4: SI2305CDS; SOT23
Q2: BSS131; SOT23
Q3, Q5: BSS138; SOT23
R1, R26: 100k; R1206
R2, R3, R4, R6, R22, R24, R28: 10k; R1206
R5, R12: 33k; R1206
R19: 150k; R1206
R20: 27k; R1206
R23: 150; R1206
R25: 100; R1206
R27: 2.2k; R1206
RST: 10-XX; B3F-10XX
SJ1: SJ2W; SJ_2
U1: ESP-WROOM-03
U2: MIC5239S; SOT223
U3, U4: WIRELESS-LORA-RFM95W#SMD

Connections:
3.3_BAT: JP2.3, JP2.4, Q4.3 (D)
+12V: C12.1, C13.1, JP2.1, JP2.2, R19.1, R27.2, U2.1 (IN)
ANEMOMETRE: C8.1, J4.5, R4.1, U1.12 (IO27)
ANT2: J2.3 (SIGNAL), U4.B8 (ANT)
ANT3: J1.3 (SIGNAL), U3.B8 (ANT)
BAT_ALERT: JP10.5, U1.23 (IO15)
CE: JP10.4, U1.14 (IO12)
DIO: SJ1.2, U1.11 (IO26)
DIO0: SJ1.1, U4.B3 (DIO0)
DIO3: SJ1.3, U4.B6 (DIO3)
DRDY1: JP5.2, U1.5 (SENSOR_VN)
GIROUETTE: C9.1, J4.3, R6.1, U1.4 (SENSOR_VP)
GND: C1.2, C2.2, C3.2, C4.2, C5.2, C7.2, C8.2, C9.2, C10.2, C12.2, C13.2, C14.2, C15.2, C16.2, C17.2, C20.2, C21.2, D2.A, J1.1 (GND), J1.2 (GND), J2.1 (GND), J2.2 (GND), J3.4, J4.4, J4.6, JP1.5, JP5.1, JP6.1, JP9.1, JP10.1, JP10.2, JP10.3, LED_G.C, LED_R.C, OPH1.1, PROG.3, PROG.4 (P1), Q2.2 (S), R12.2, R24.2, R26.1, R28.2, RST.3, RST.4 (P1), U1.1 (GND), U1.15 (GND), U1.38 (GND), U1.GND, U2.2 (GND), U2.4 (GND), U3.A1 (GND.1), U3.A8 (GND.2), U3.B7 (GND.3), U4.A1 (GND.1), U4.A8 (GND.2), U4.B7 (GND.3)
IO0: JP6.6, PROG.1 (S), PROG.2 (S1), R1.2, U1.25 (IO0)
LDR: OPH1.2, R22.2
LED_G: R25.1, U1.10 (IO25)
LED_R: R23.1, U1.9 (IO33)
MEASURE: Q2.1 (G), Q3.1 (G), Q5.1 (G), R12.1, U1.16 (IO13)
MISO: U1.31 (IO19), U3.A2 (MISO), U4.A2 (MISO)
MOSI: U1.37 (IO23), U3.A3 (MOSI), U4.A3 (MOSI)
unnamed: Q1.1 (G), Q2.3 (D), R5.1
unnamed: Q3.3 (D), R19.2
unnamed: Q5.3 (D), R20.1
unnamed: LED_R.A, R23.2
unnamed: LED_G.A, R25.2
unnamed: D2.C, Q4.1 (G), R26.2, R27.1
PLUVIOMETRE: C7.1, J3.5, R3.1, U1.8 (IO32)
RFM_NSS: U1.29 (IO5), U4.A5 (NSS)
RFM_NSS2: U1.26 (IO4), U3.A5 (NSS)
RFM_RST: U1.13 (IO14), U3.A6 (RST), U4.A6 (RST)
RFM_SCK: U1.30 (IO18), U3.A4 (SCK), U4.A4 (SCK)
RST: C3.1, JP6.2, R2.1, RST.1 (S), RST.2 (S1), U1.3 (EN)
RX: JP6.5, U1.34 (RXD)
SCK: JP1.3, JP2.5, U1.36 (IO22)
SCL1: JP5.4, U1.27 (IO16)
SDA: JP1.4, JP2.6, U1.33 (IO21)
SDA1: JP5.3, U1.28 (IO17)
TX: JP6.4, U1.35 (TXD)
V+: C10.1, C16.1, C17.1, JP1.1, JP1.2, JP1.6, JP5.5, JP9.2, Q1.3 (D), R3.2, R4.2, R6.2, R22.1, U3.B4 (3.3V)
VALID: U1.24 (IO2)
VALIM: C20.1, Q3.2 (S), R24.1, U1.7 (IO35)
VBAT: C21.1, Q5.2 (S), R28.1, U1.6 (IO34)
VCC: C1.1, C2.1, C4.1, C5.1, C14.1, C15.1, JP6.3, Q1.2 (S), Q4.2 (S), R1.1, R2.2, R5.2, R20.2, U1.2 (3V3), U2.3 (OUT), U4.B4 (3.3V)

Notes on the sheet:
If DTR is LOW, toggling RTS from HIGH to LOW resets to run mode. If RTS is HIGH, toggling DTR from LOW to HIGH resets to bootloader.
Boot Mode Configuration Pin Default Boot Download GPIO0 1 1 0 U0TXD 1 1 x GPIO2 0 x 0 GPIO4 0 x x MTDO 1 x x GPIO5 1 1 x If U0TXD, GPIO2, GPIO5 are floating, GPIO0 determines boot mode
V 1.55
TSL Sensor
BME SENSOR
Pluviometre
Anémomètre
Girouette

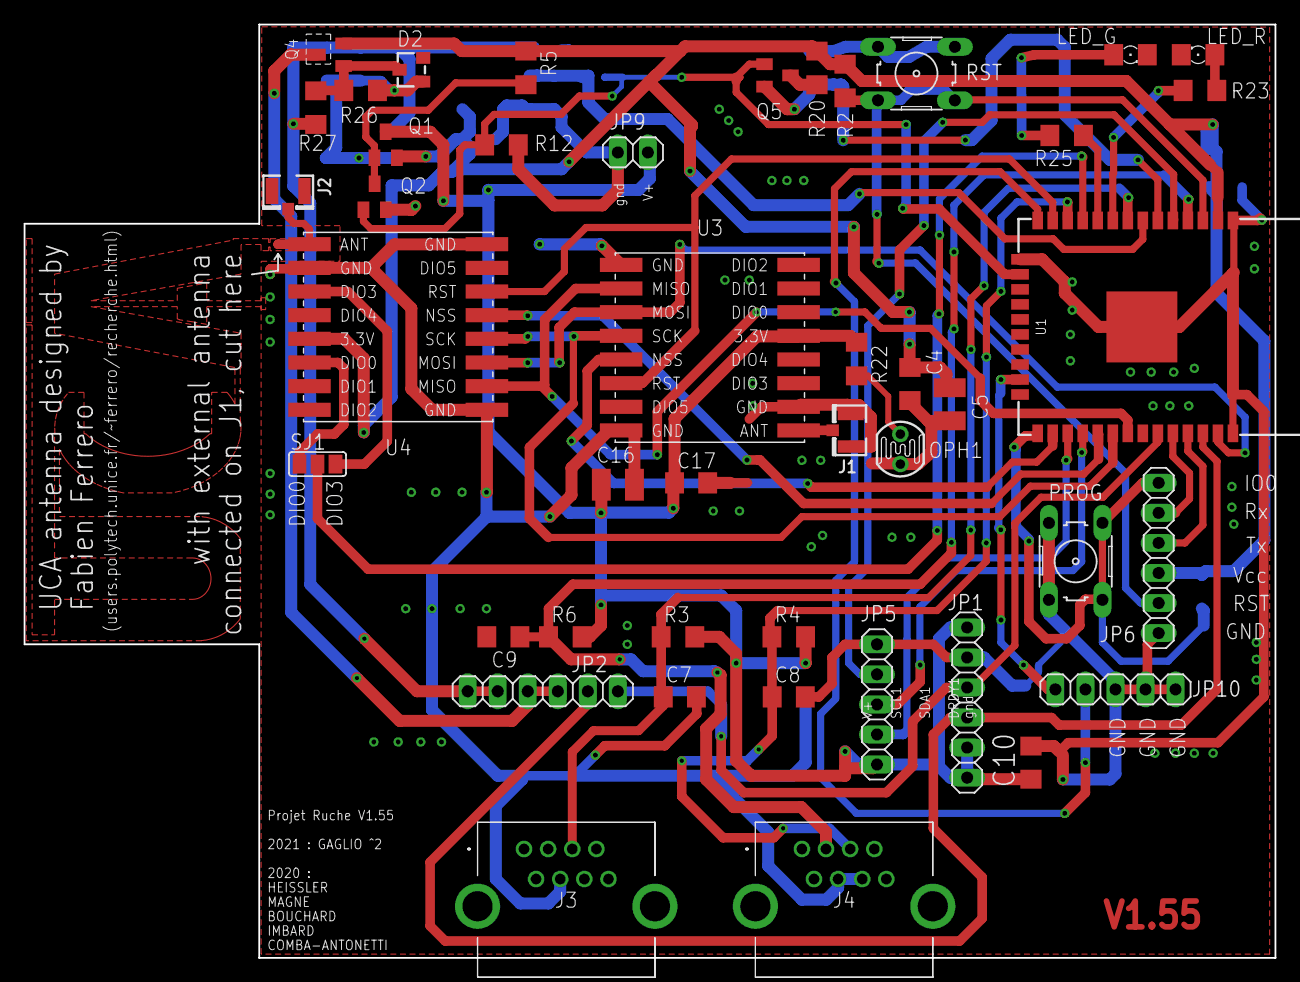
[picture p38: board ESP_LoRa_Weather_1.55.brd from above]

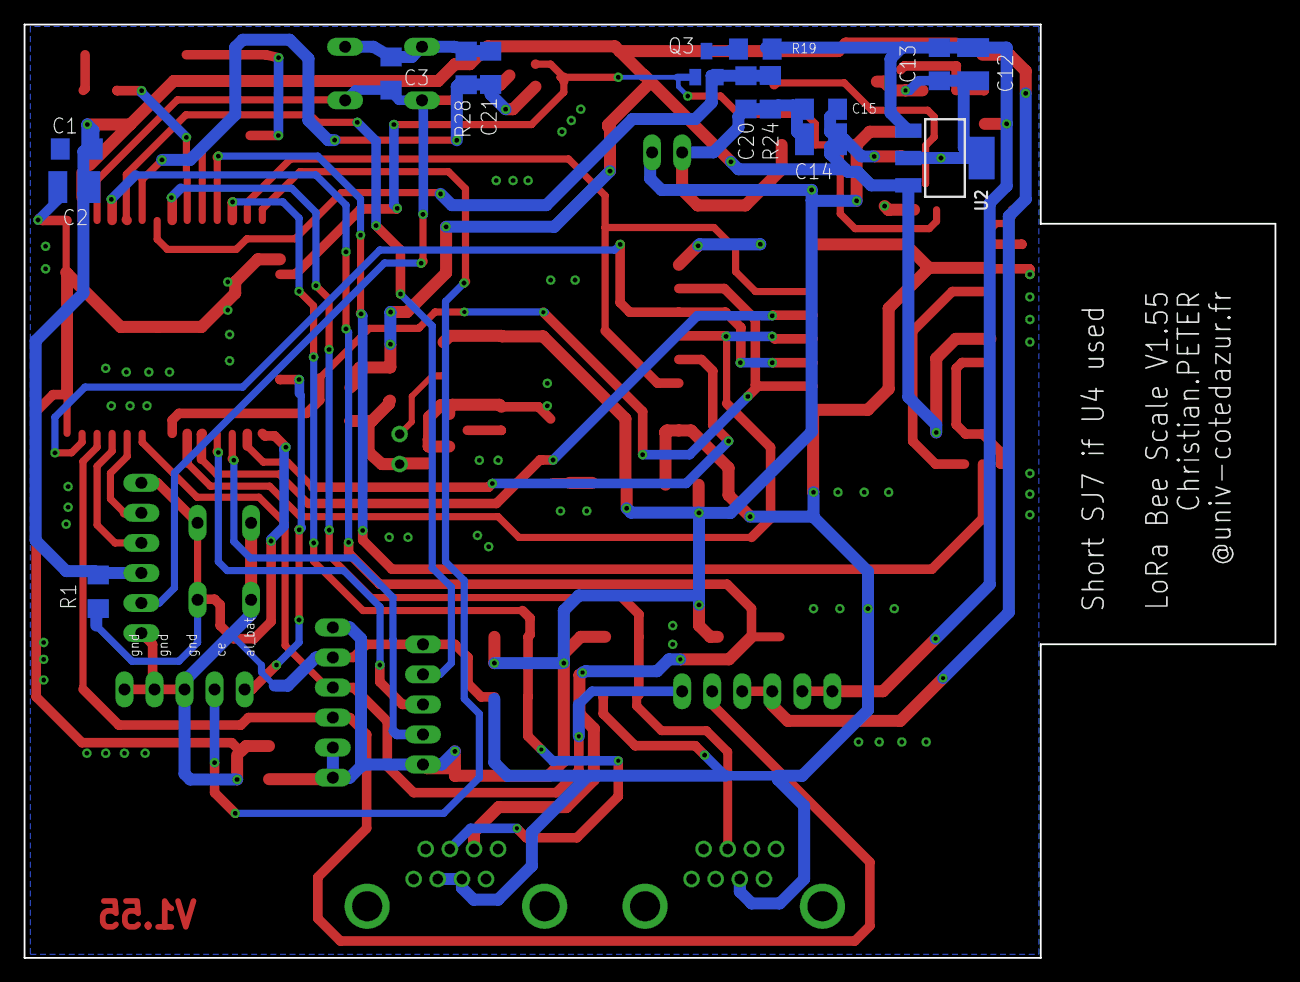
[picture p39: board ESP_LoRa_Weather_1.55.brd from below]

Board: 2 copper layers, 105.8 x 78.9 mm, 59 parts (15 on the bottom side), 42 nets.

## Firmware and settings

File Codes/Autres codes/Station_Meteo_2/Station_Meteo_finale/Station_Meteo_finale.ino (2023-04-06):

//PROJET STATION METEO
//AMBRE ALLOUIS - SOLENE GUILLAUME
//ANNEE 2022-2023


//LIBRARIES
#include <Adafruit_BusIO_Register.h>
#include <Adafruit_I2CDevice.h>
#include <Adafruit_I2CRegister.h>
#include <Adafruit_SPIDevice.h>
#include <Adafruit_BME280.h>
#include <Adafruit_Sensor.h>
#include "Adafruit_TSL2591.h"
#include <ESP32TimerInterrupt.h>
#include <ESP32TimerInterrupt.hpp>

//#include "definition.h"
#include "donnees.h"
#include "esp_lora.h"
#include "WiFi.h"

//PINNING DE L'ESP
#define MEASURE 13
#define LED_R 33
#define LED_G 25
#define ANEMOMETRE 27
#define PLUVIOMETRE 32
#define GIROUETTE 36

Adafruit_BME280 bme;
Adafruit_TSL2591 tsl = Adafruit_TSL2591(2591);

//void calculateValues_BME_TSL();
//void printValuesSerial();

//VARIABLES GLOBALES
#define RAYON 0.07 // rayon de l'anemometre de 7 cm
//#define B1000000 64
//#define B110 6
#define uS_TO_S_FACTOR 1000000  /* Conversion factor for micro seconds to seconds */
#define TIME_TO_SLEEP  15        /* Time ESP32 will go to sleep (in seconds) A multiplier par 60 pour 15 minutes */

int compt=0 ;
float quantiteEau = 0;
unsigned long startTime_P;  
unsigned long currentTime_P;
const unsigned long period_P = 10000;

float temperature = 0.0;
float pression = 0.0;
float humidite = 0.0;
float luminosite = 0.0;
float vitesseVent;

int tourAnemo=0 ;
unsigned long startTime_A;  
unsigned long currentTime_A;
unsigned long delayTime;
const unsigned long period_A = 10000;

RTC_DATA_ATTR int nb_wakeup = 0;

void print_wakeup_reason(){
  esp_sleep_wakeup_cause_t wakeup_reason;

  wakeup_reason = esp_sleep_get_wakeup_cause();

  switch(wakeup_reason)
  {
    case ESP_SLEEP_WAKEUP_EXT0 : Serial.println("Wakeup caused by pluviometre"); break;
    case ESP_SLEEP_WAKEUP_TIMER : Serial.println("Wakeup caused by timer"); break;
    default : Serial.printf("Wakeup was not caused by deep sleep: %d\n",wakeup_reason); break;
  }
}

void setup() {
  //Supply ON
  pinMode(MEASURE, OUTPUT);
  digitalWrite(MEASURE, HIGH);
  //Serial monitor port
  Serial.begin(9600);
  //Pin definition
  pinMode (LED_R, OUTPUT);
  pinMode (LED_G, OUTPUT);
  pinMode (ANEMOMETRE, INPUT);
  pinMode (PLUVIOMETRE, INPUT);
  pinMode (GIROUETTE, INPUT);
  //Luxmetre
  bme.begin(0x76);
  tsl.begin(0x76);
  tsl.setGain(TSL2591_GAIN_MED); 
  tsl.setTiming(TSL2591_INTEGRATIONTIME_300MS);
  // LoRa
  SPI.begin(SCK, MISO, MOSI);
  LoRa.setPins(SS, RST, DI0);
  //Interrupts
  attachInterrupt(PLUVIOMETRE,comptage,FALLING);
  attachInterrupt(ANEMOMETRE,comptageAnemo,FALLING) ; 
  //Variable definition
  startTime_P = millis();
  lecture_donnee();
  //wakeup
  //Increment boot number and print it every reboot
  ++nb_wakeup;
  Serial.println("Boot number: " + String(nb_wakeup));
  //Print the wakeup reason for ESP32
  print_wakeup_reason();

  /*  First we configure the wake up source  We set our ESP32 to wake up every 5 seconds  We set our ESP32 to wake up every rain interruption  */
  esp_sleep_enable_timer_wakeup(TIME_TO_SLEEP * uS_TO_S_FACTOR);
  Serial.println("Setup ESP32 to sleep for every " + String(TIME_TO_SLEEP) +
  " Seconds");
  esp_sleep_enable_ext0_wakeup(GPIO_NUM_32, 1);
  
  Serial.println("Going to sleep now");
  
  delay(1000);
  Serial.flush(); 
  esp_deep_sleep_start();
  Serial.println("This will never be printed");
  
}

void lecture_donnee() {
  digitalWrite(LED_G, HIGH);
  delay(100);
  digitalWrite(LED_G, LOW);
  delay(100);
  girouette();
  //Toutes les secondes
  currentTime_P = millis();
  if (currentTime_P - startTime_P >= period_P)//test whether the period has elapsed
  { 
    Serial.print("\n-------------------------------------\n");
    //Pluviomètre
    Serial.print("Quantité d'eau : ");
    Serial.print(calcul_quantite_eau());
    Serial.print(" mm \n");
    //LuxHumTemp
    calculateValues_BME_TSL();
    printValuesSerial();
    //Anemometre
    Anemo();
    //LoRa
    LoRa_Envoi();
    //Remise à 0 du compteur temporel
    startTime_P = currentTime_P;
  }
}

void loop(){
  //rien
}

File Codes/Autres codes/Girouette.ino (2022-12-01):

#define MEASURE 13
#define LED_R 33
#define LED_G 25
//#define ANEMOMETRE 12
//#define PLUVIOMETRE 8
#define GIROUETTE 36
//#define GIROUETTE 32

void setup() {
  pinMode(MEASURE, OUTPUT);
  digitalWrite(MEASURE, HIGH);
  pinMode (LED_R, OUTPUT);
  pinMode (LED_G, OUTPUT);
//pinMode (ANEMOMETRE, OUTPUT);
//pinMode (PLUVIOMETRE, OUTPUT);
  pinMode (GIROUETTE, INPUT);
  Serial.begin(9600);
}

void loop() {
  
  digitalWrite(LED_G, HIGH);
  delay(100);
  digitalWrite(LED_G, LOW);
  delay(100);

  int sensorValue = analogRead(GIROUETTE);
  String directionVent;
  if (sensorValue > 3216 && sensorValue <= 3600 )
  {
    directionVent = "Ouest";
  }
  if (sensorValue > 2869 && sensorValue <= 3216)
  {
    directionVent = "Nord Ouest";
  }
  if (sensorValue > 2646 && sensorValue <= 2869)
  {
    directionVent = "Nord Ouest Ouest";
  }
  if (sensorValue > 2417 && sensorValue <= 2646)
  {
    directionVent = "Nord";
  }
  if (sensorValue > 2121 && sensorValue <= 2417)
  {
    directionVent = "Nord Nord Ouest";
  }
  if (sensorValue > 1934 && sensorValue <= 2121)
  {
    directionVent = "Sud Ouest";
  }
  if (sensorValue > 1645 && sensorValue <= 1934)
  {
    directionVent = "Sud Ouest Ouest";
  }
  if (sensorValue > 1312 && sensorValue <= 1645)
  {
    directionVent = "Nord Est";
  }
  if (sensorValue > 1008 && sensorValue <= 1312)
  {
    directionVent = "Nord Nord Est";
  }
  if (sensorValue > 725 && sensorValue <= 1008)
  {
    directionVent = "Sud";
  }
  if (sensorValue > 543 && sensorValue <= 725)
  {
    directionVent = "Sud Sud Ouest";
  }
  if (sensorValue > 338 && sensorValue <= 543)
  {
    directionVent = "Sud Est";
  }
  if (sensorValue > 184 && sensorValue <= 338)
  {
    directionVent = "Sud Sud Est";
  }
  if (sensorValue > 111 && sensorValue <= 184)
  {
    directionVent = "Est";
  }
  if (sensorValue > 64 && sensorValue <= 111)
  {
    directionVent = "Nord Est Est";
  }
  if (sensorValue > 1 && sensorValue <= 64)
  {
    directionVent = "Sud Est Est";
  }
  Serial.print("Direction du vent : ");
  Serial.println(directionVent);
}

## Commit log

2022-09-01 Create SoleneGUILLAUME.md
    Cahier de bord du projet Ruche connectée Module météo de Solene Guillaume
2022-09-01 Rename SoleneGUILLAUME.md to Rapports de séance/SoleneGUILLAUME.md
2022-09-01 Rename AmbreALLOUIS.md to Rapports de séance/AmbreALLOUIS.md
2022-12-01 Create Liste des bibliothèques
2022-12-02 Update Liste des bibliothèques
2022-12-02 Rename Liste des bibliothèques to Liste des bibliothèques.md
2022-12-02 Update Liste des bibliothèques.md
2023-01-06 Create README.md
    Explication des ports
2023-04-06 Ajout de périphériques

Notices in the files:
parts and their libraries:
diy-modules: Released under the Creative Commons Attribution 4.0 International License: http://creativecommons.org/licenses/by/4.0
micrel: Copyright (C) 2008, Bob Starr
